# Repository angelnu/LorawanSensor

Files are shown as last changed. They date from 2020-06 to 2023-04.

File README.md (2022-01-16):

# STM32 Low Power LoraWan Sensors

This project provides a framework to easily build LoraWan devices. The requirements are:
- sensors that could run without replacing batteries during the life cycle of the device
- small size
- easy to build and program (need a 20-30)
- simple to create a new type: just a new file
- cost bellow 20€
- resist the outside weather with easy to 3D print cages

The sensor can work on a CR123 battery for 20 years (self-discharge of the battery being the main factor). It sends the battery voltage and (optionally) the temp of the MCU (using factory calibration).

For each new detected device it generates unique LoraWan keys and upload them to flash. This way the same firmware can be used for multiple instances of the same board.

**NOTE**: Do not put the config directory in a public repository. Instead save as extra home/private repository so you have versioning while keeping your keys private!

Download commands might be used to query or modify the configuration. See the commands section bellow.

## Bill of Materials
Devices can be built for ca 10-20€ ussing the following parts:
- STM32 MCU - any of the following:
  - STM32L412KB (3 €) - prefered: 128KB RAM for a future firmware OTA update
    - STM32L412KBT6 128K Flash,  8K RAM, LQFP-32
  - STM32L412K8 (2.5 €) - same as STM32L412KB but only 64K Flash
    - STM32L412K8T6 64K Flash,  8K RAM, LQFP-32
  - STM32L010K8 (1.5 €) - cheaper MCO+, slower, less memory, not tem and slightly higher consumption
    - STM32L412K8T6 64K Flash,  8K RAM, LQFP-32 
- RFM95W (3.5 € via Aliexpress, 3x this price if bought in Europe)
- RC123a battery and holder (2€ via Aliexpress, 2x this price if bought in Europe)
- PCB (2-5 € when ordering 12 from [Aisler](https://aisler.net) ) - see [Devices](devices) folder for the sources and the uploaded PCBs to [Aisler](https://aisler.net)
- 3D-printed boxes - see cages in [Devices](devices) folder
- some SMT components (1 €) - see schematics in [Devices](devices) folder

## Downlink commands

Downlink commands are used to query and/or modify the device settings without having to reprogram the flash. Each command uses one byte plus optional data depending on the command. The commands are implemtented in the `lorawan_process_command` at [lorawan.cpp](src/lorawan.cpp#L188)

Commands will be queued and transferred to the device after the next uplink transfer. Multiple commands can be queued but be carefull not to exceed to the watdown timeout or the device will get reset.

Commands:
- 0x00 - READ configuration
  - Description: Returns the configuration of the device. See [device_config_t](src/config.h#L23) for more details on the struct
  - Additional downlink bytes: none
  - Example output: 02 03 3C00 05 3C 6400 5802 01 0A 05 FF
- 0x01 - Reset config to the default
  - Additional downlink bytes: none
- 0x02 - Sets the configuration
  - Additional downlink bytes: config as returned by the 0x00 command
  - Example input: 02 02033C00053C64005802010A05FF
- 0x05 - Read Device UID
  - Additional downlink bytes: none
  - Output: 12 bytes with STM32 UID
- 0x06 - Read firmware GIT commit
  - Additional downlink bytes: none
  - Output: ASCII string
- 0x07 - Read firmware BUILD date
  - Additional downlink bytes: none
  - Output: ASCII string

## Firmware

This project requires [Platformio](https://platformio.org/) and the [STM32 Cube Programmer](https://www.st.com/en/development-tools/stm32cubeprog.html). Both need to be installed and available in the PATH.

Keys for each detected device will be stored under `config/devices.ini`. Before you run for the first time please create the file and include your app EUI (or modify afterwards). You can create this by registering a new app at the [TTN](https://console.thethingsnetwork.org/applications) console. The file should have:
```
[global]
appeui = <your app EUI>
```
If you run without creating the file first then the programmer will create a dummy APPEUI which you will need to modify. You can keep the config folder into its own git repository but please keep it private! On checkout you might use the [this script](checkout_keys_repo.sh) to check it out.

For programming either use the platformio UI or any of the CLI commands proposed for the device.

If you connect a serial interface while booting you should see the following:
```
Settings unchanged
DEVICE VERSION: 3
DEVICE CONFIG: 0x02033C00053C64005802010A05FF
Device UID: 0x3200230006504D3843353720
BUILD DATE: Jun 21 2020
BUILD TIME: 18:07:48
COMMIT ID: e3d1d3b5d34d39d88d90022d6fe365ebce3887b5
APPEUI: 0x.....
DEVEUI: 0x....
Starting
7579 Sending.. 18248 TX_COMPLETE
```

## Adding new devices

1. Add a section to `platformio.ini` for your device. The key part is to have a dedicated `-D SENSOR_<PCB name>_<sensor name>_<MCU name>` (such as `-D SENSOR_GENERIC_DISTANCE_SMT32`) -> this will be needed in the next step.
  - If you are just using the generic PCB then you can copy `Basic v1` and modify to your needs
  - If you are creating your own PCB based on the STM32 MCU then you can copy `Generic v1` and modify to your needs
  - If you use a different MCU then you will need to create your own target extending `base` and `base_debug`. Please notice that you will in this case have to add support for the new MCU in multiple areas of the code where the MCU is relevant: the code has been tested with STM32 (mainly) and atmega32.
2. Add a new cpp file to `src/devices/` for your new device. The namming convention is <PCB type>_<device name>_<MCU family>.cpp. If you are using a STM32 CPU you should consider copying `generic_basic_stm32.cpp` which does not depend on any external sensors to work and then add your own sensors to it. You need to make this file to only get included and compiled when `SENSOR_<PCB name>_<sensor name>_<MCU name>` is defined.
3. Add to `devices.h` a section for your device where you set your `device_config_device_t`. This struct includes what persistent settings your device needs. These settings can later be modified via a LORAWAN command.
4. Documment your device in the `devices` folder. This folder structure is:
   - _<PCB name>_
     - _cages_: instructions and files to 3D print cages for devices
     - _KiCad_: Schematics and PCBs created with KiCad
     - _pictures_: pcitures embedded in markdown readme
     - _README_: instructions, pictures and links for devices. It is structured with a chapter for each device sharing the same PCB and a subcharter for each mayor version of the device. 

## ToDos
- Firmware OTA update

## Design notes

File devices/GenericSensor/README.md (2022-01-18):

# Generic Sensor PCB

This device exposed all available GPIOs from the 32 pin STM32 so external sensors can be attached. Multiple use cases are listed bellow.

- GenericSensor_PCB_full_view

## Versions of the PCB

### Generic Sensor v2

This verssion is backwards compatible (same posssitions for all components, even the v1 stencil might be used) but adds support for additional pull-ups or pull-downs. Check the schematic bellow to understand the options: there are two sets of solder jumpers that allow pull-up or pull-down selection. Also using 0R you can enable additional 3V and GND outputs.

- [Aisler PCB project](https://aisler.net/p/LVXPWPMZ)
- [PCB STEP model](KiCad/GenericSensor_v2.step)
- [KiCad model](KiCad\GenericSensor_v2-backups/GenericSensor_v2.kicad_pro)
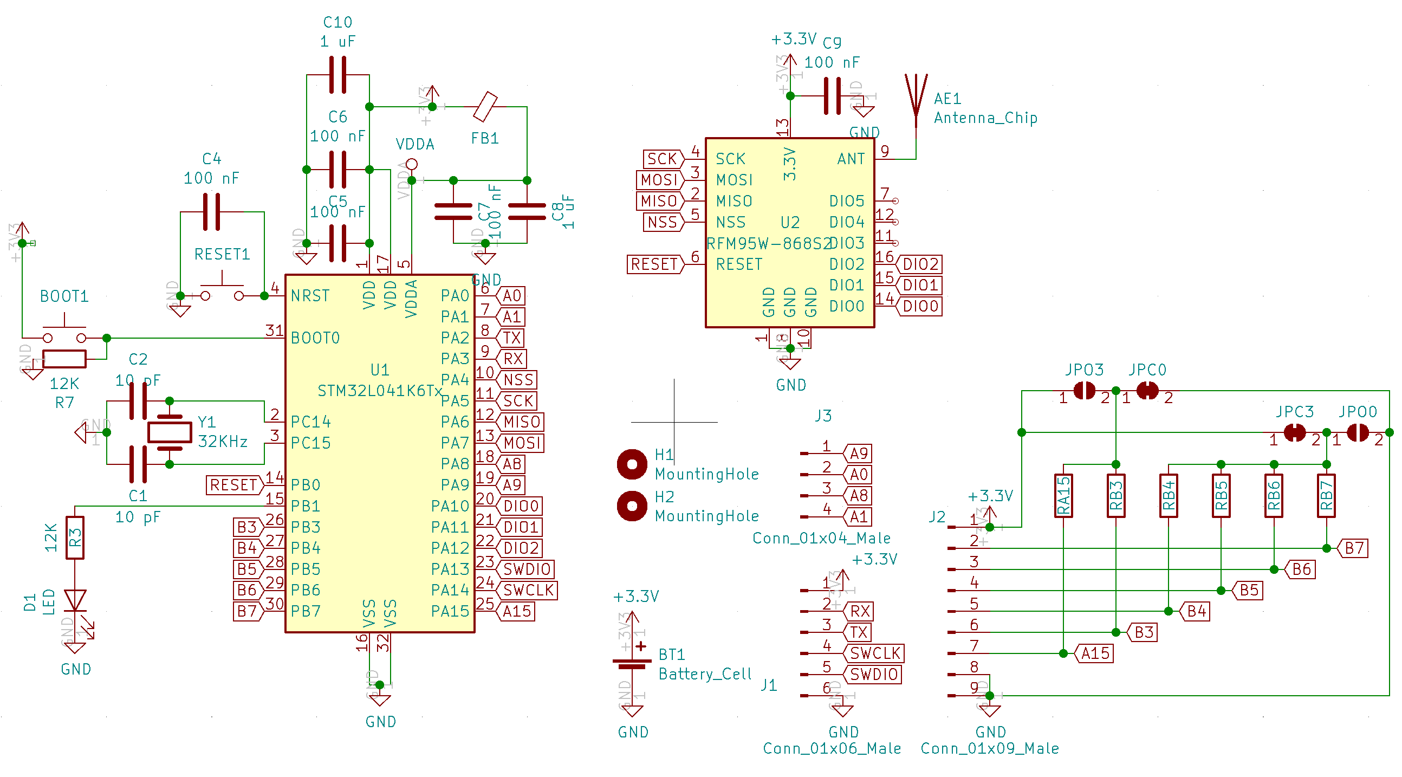
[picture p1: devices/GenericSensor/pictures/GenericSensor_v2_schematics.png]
Schematics Preview
- 
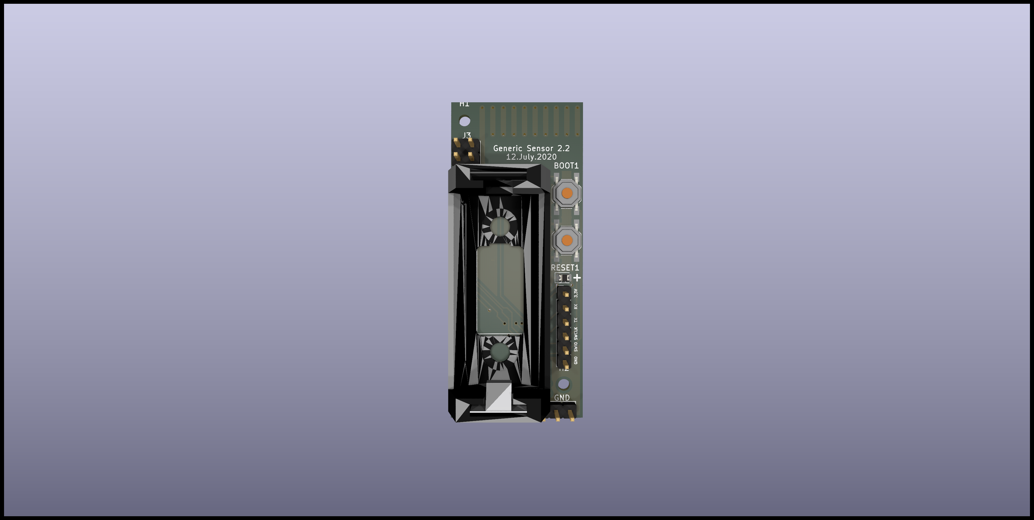
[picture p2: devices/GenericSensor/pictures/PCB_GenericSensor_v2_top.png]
PCB Top render
- 
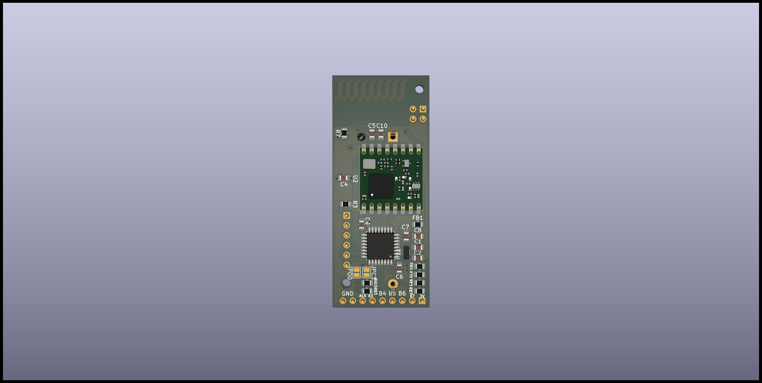
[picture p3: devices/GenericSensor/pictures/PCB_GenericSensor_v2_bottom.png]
PCB Bottom render
- 

### Generic Sensor v1

This is the first version without any unneded HW. It is optimised to make it easy to esamble with only the programing pins and the battery holder not being SMD components. It does not external pull-ups so it relays into the internal ones in the MCU -> this is not the best for battery life (40 KOhms drag ca 75 uA) so v2 was develop to allow use larger (such as 10 MOhms) instead.

Since v2 is backwards compatible there is no need to use v1 anymore.

- [Aisler PCB project](https://aisler.net/p/YFVFQBHD)
- [SoilSensor.sch](KiCad/GenericSensor_v1.sch)
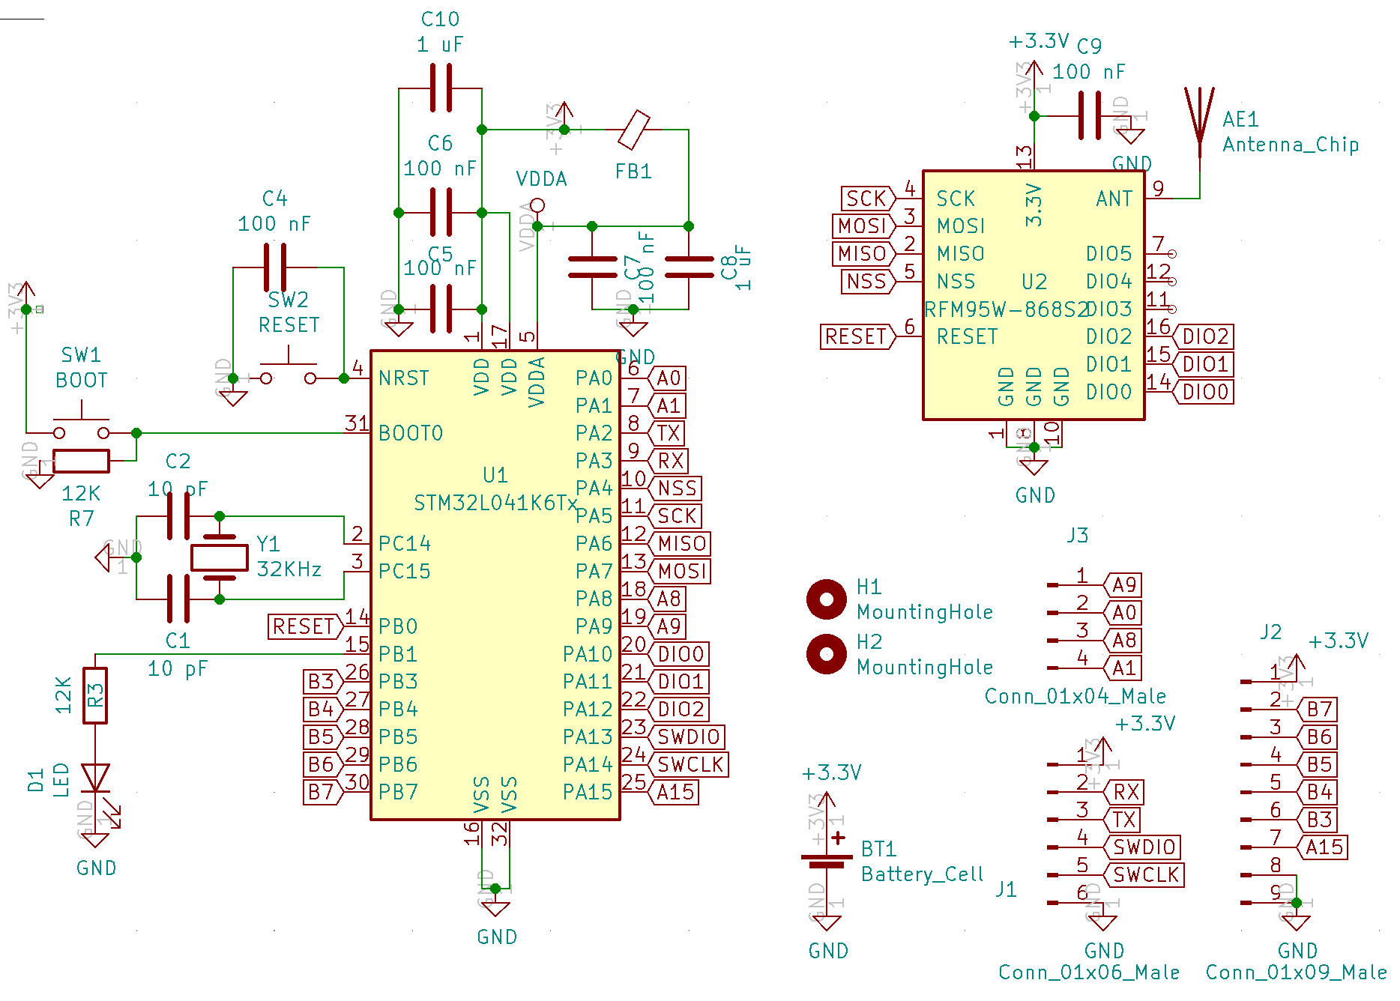
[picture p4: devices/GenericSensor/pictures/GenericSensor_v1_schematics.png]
Schematics Preview
  - 
- [SoilSensor.kicad_pcb](KiCad/GenericSensor_v1.kicad_pcb)

## Use Cases

## Basic v1

This is mainly for debugging and as base for the other use cases. It is just the generic sensor and its embedded battery and temperature sensors.
- Sensor: none extra, just battery voltage and temperature
- Power consumption:
  - measurements: 0,4 mA, 30 ms, 1 measurement/minute
  - transmission: 120 mA, 50 ms, sending once/hour
  - iddle: 300 uA, 2 s, sending once/hour
  - deep sleep: 2 uA
  - battery: 1400 mAh
  - theoretical batery live (no auto-discharge): 39 years
- PINs: none of the external pins used
- Firmware:
  For programming either use the platformio UI or any of the following CLI commands:
  - `pio run -t upload -e generic_basic_v1` - PCB v2, STM32 L4
  - `pio run -t upload -e generic_basic_v1_debug` - PCB v2, STM32 L4, debug
- [3D Printed cage](cages):
  - None
- BUGS:
  - None so far

### Distance Sensor v1

Used to detect when a car is parked in a parking lot.

- Sensor:
  - Lidar [vl53l1x](https://www.st.com/en/imaging-and-photonics-solutions/vl53l1x.html): consumption small enough to be powered through a PIN without a mosfet - not low power enough to keep power during deep sleep. It can measure up to 4 meters.
    - Used [Melopero board](https://www.melopero.com/shop/sensori/prossimita/melopero-vl53l1x-time-of-flight-long-distance-ranging-sensor-breakout/) since it was quickly available in Amazon
    - Ordered some with cover from [China](https://de.aliexpress.com/item/4000110308676.html)
- Power consumption:
  - measurements: 1,5 mA, 120 ms, 1 measurement/minute
  - transmission: 120 mA, 50 ms, sending once/hour
  - iddle: 300 uA, 2 s, sending once/hour
  - deep sleep: 2 uA
  - battery: 1400 mAh
  - theoretical batery live (no auto-discharge): 23 years
- PINs:
  - PB7 -> vl53l1x I2C SDA
  - PB6 -> vl53l1x I2C SCL
  - PB5 -> vl53l1x VIN
  - GND -> vl53l1x GND
- Firmware:
  For programming either use the platformio UI or any of the following CLI commands:
  - `pio run -t upload -e distance_v1` - PCB v2, STM32 L4
  - `pio run -t upload -e distance_v1_debug` - PCB v2, STM32 L4, debug
- [3D Printed cage](cages/distance):
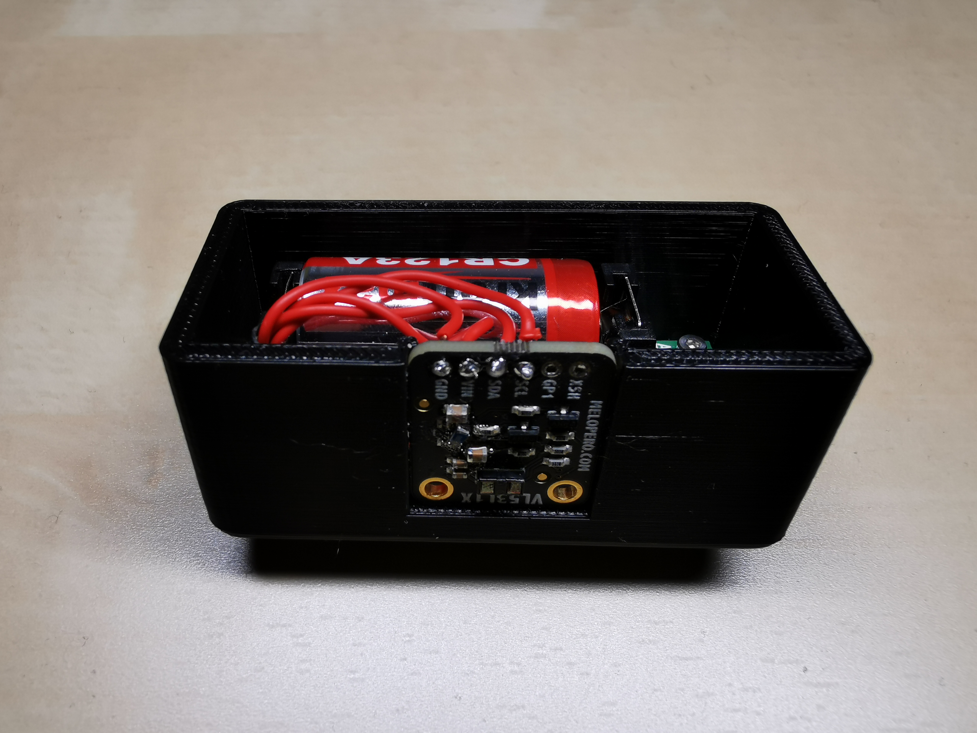
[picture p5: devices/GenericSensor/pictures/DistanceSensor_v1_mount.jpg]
Cage Mount
  - 
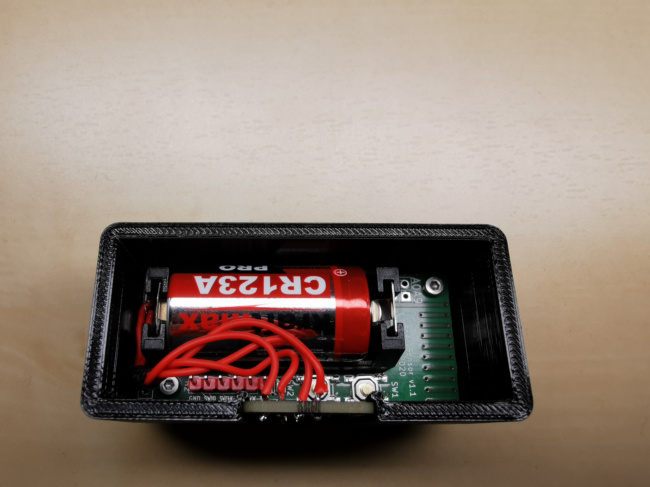
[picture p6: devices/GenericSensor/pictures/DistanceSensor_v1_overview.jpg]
PBC view
  - 
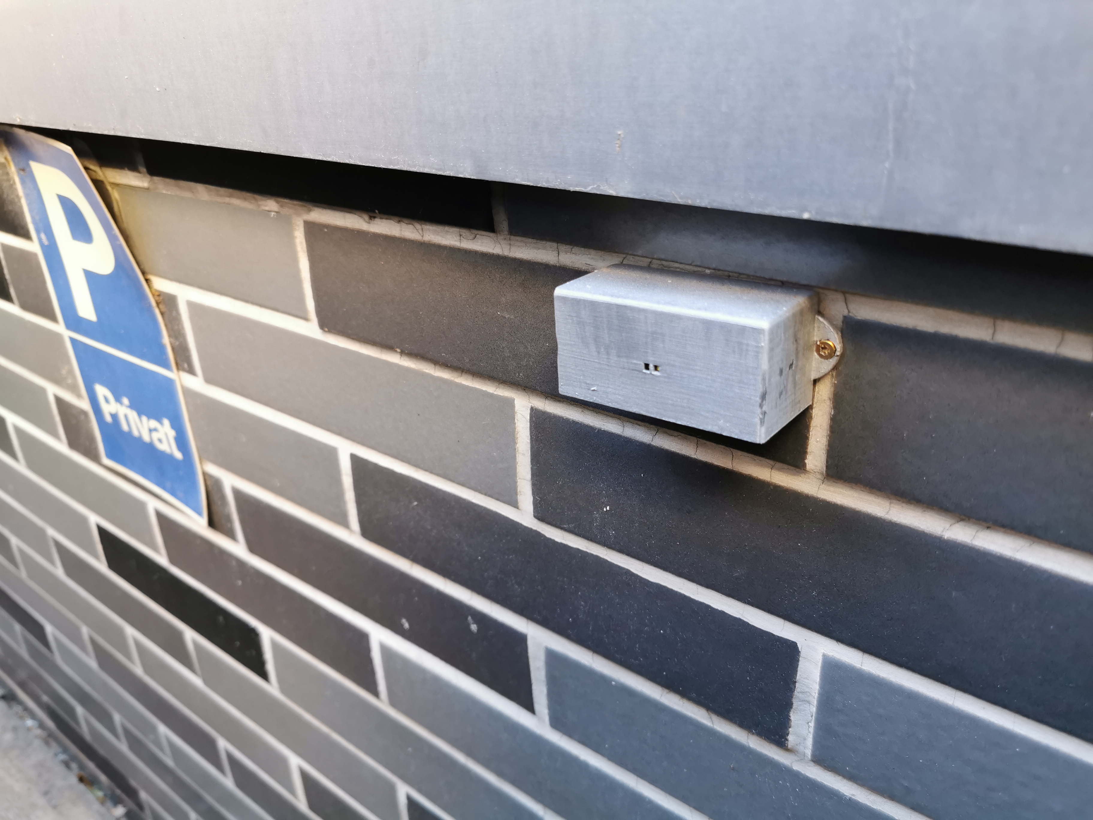
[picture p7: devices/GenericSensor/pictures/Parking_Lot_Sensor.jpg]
Mounted Cage
  - 
- BUGS:
  - None so far
  
### Door Sensor v1

This sensor tracks the state (open/closed) of up to 4 doors or windows. It supports two modes:
- simple: the state of the door/window is directly reported as soon as it changes
- perssistent mode (or post-mode): once the door is opened once is reported as open even if it gets closed afterwards. A second sensor is used to reset the reported door status back to closed. The reset is typically associated to a second door used to pick up the post but it could also get connected to a button that plays the same role.

- Sensor:
  - 1-8 x [Reed Contact N/O Magnetic Induction Switch](https://www.amazon.de/gp/product/B07SZDGXLC): this switch reports open so far no magnet is close. This would correspond to the door/window being open.
  - 1-8 x Circular magnet
  - 1-8 x 10 MOhms resistor
- Power consumption:
  - measurements: 1,5 mA, 40 ms, 2 measurement/day (post mode)
  - transmission: 120 mA, 50 ms, sending 2/day
  - iddle: 300 uA, 2 s, sending once/hour
  - deep sleep: 2 uA + (0.3 * number_of_sensors)
  - battery: 300 mAh
  - theoretical batery live (no auto-discharge): 23 years
- PINs (using PCB v1): each sensor needs a big (10 MOhm resistor) pull-up.
  - VCC  -> pull-up resistors
  - PB7  -> cannot be used for interrupts - conflicts with MOSI
  - PB6  -> cannot be used for interrupts - conflicts with MISO
  - PB5  -> pull-up resistor (RB5) and door 1 reed switch
  - PB4  -> pull-up resistor (RB4) and door 1 reset reed switch
  - PB3  -> pull-up resistor (RB3) and door 2 reed switch
  - PA15 -> pull-up resistor (RA15) and door 2 reset reed switch
  - PA0  -> pull-up resistor (external) and door 3 reed switch (need to uncomment in `platformio.ini`)
  - PA1  -> pull-up resistor (external) and door 3 reset reed switch (need to uncomment in `platformio.ini`)
  - PA8  -> pull-up resistor (external) and door 4 reed switch (need to uncomment in `platformio.ini`)
  - PA9  -> pull-up resistor (external) and door 4 reset reed switch (need to uncomment in `platformio.ini`)
  - GND -> reed switches
- PINs (using PCB v2) for 2 doors:
  - VCC: not used
  - RB7, RB6, RB5, RB4: 10 MOhms (0805 type)
  - RB3, RA15: 0R (0805 type)
  - Solder jumpers umodified
  - PB7  -> door 1 reed switch
  - PB6  -> reset for door 1 (or door 3) reed switch
  - PB5  -> door 2 reed switch
  - PB4  -> reset for door 2 (or door 4) reed switch
  - PB3, PA15 and both GNDs: any of the above reed switches
- Firmware:
  For programming either use the platformio UI or any of the following CLI commands:
  - `pio run -t upload -e distance_v1` - PCB v2, STM32 L4
  - `pio run -t upload -e distance_v1_debug` - PCB v2, STM32 L4, debug
- [3D Printed cage](cages/door):
  - [Fusion 360 file](https://a360.co/3GygWqv)
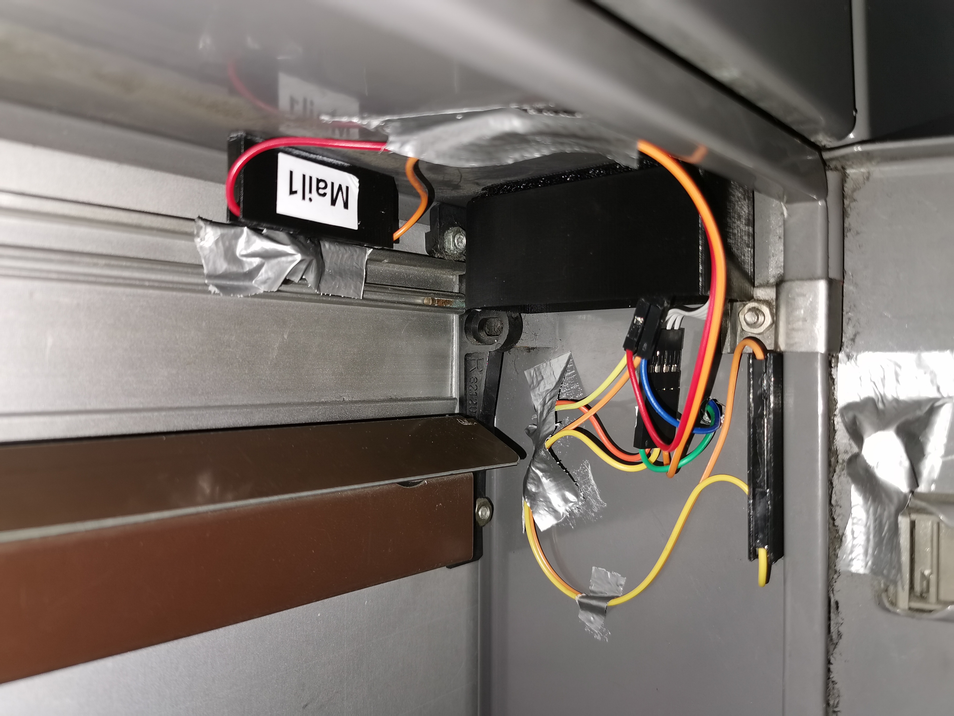
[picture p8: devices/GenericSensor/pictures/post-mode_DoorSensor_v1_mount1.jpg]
Mounted Cage view 1
  - 
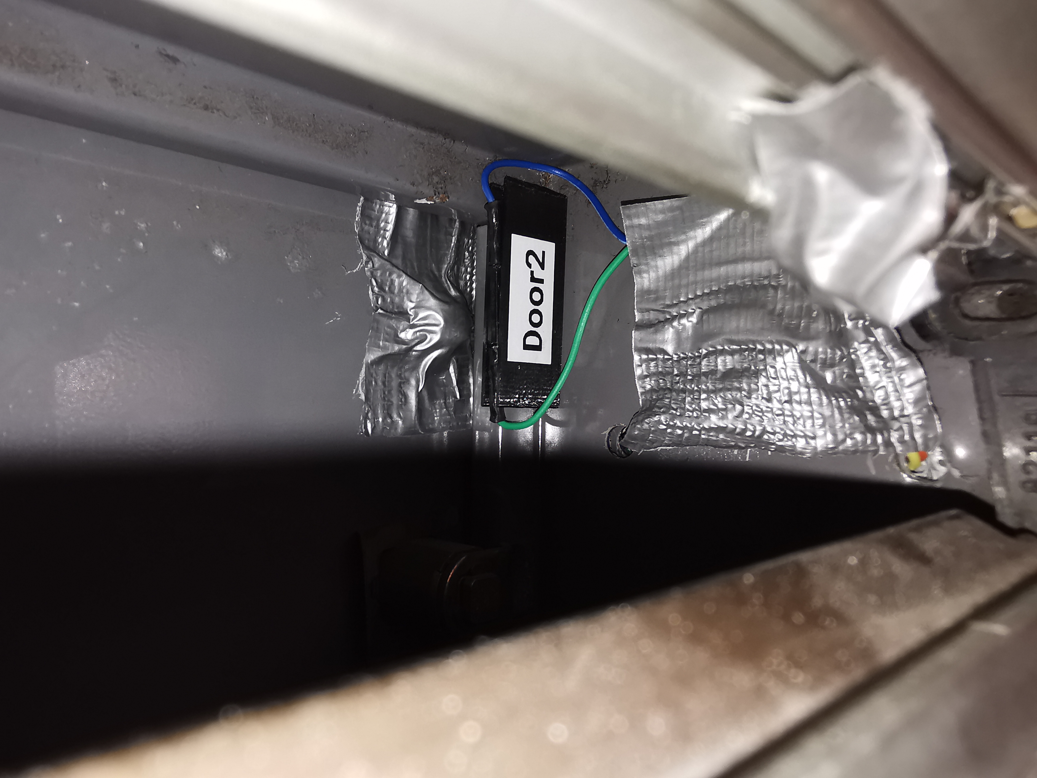
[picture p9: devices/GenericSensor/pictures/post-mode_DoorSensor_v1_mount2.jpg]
Mounted Sensor view 2
  - 
- BUGS:
  - None so far

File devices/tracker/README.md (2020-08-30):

# Tracker

This is a GPS tracker including a move sensor and a distance sensor (not in the PCB). It also routes most of the MCU pins to a connector so additional sensors might be connected.

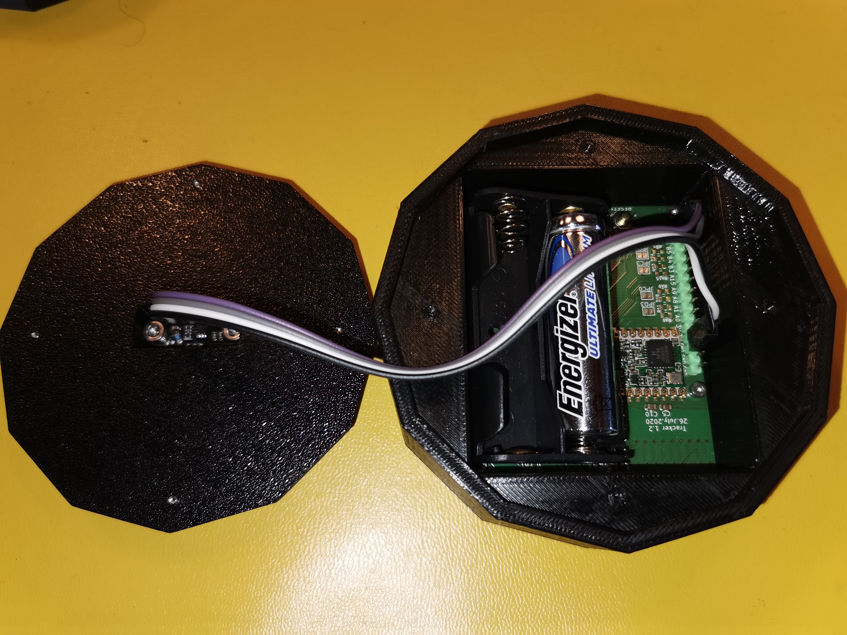
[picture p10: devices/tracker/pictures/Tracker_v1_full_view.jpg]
Full mount Tracker v1
- 

## Tracker v1 (WIP)

In this version a distance sensor is also used to measure the gasoil level in a vehicle.

This is Work In Progress - Firmware not ready and PCB not tested yet.

- [Aisler PCB project](https://aisler.net/p/XNCQBQQY)
- [Tracker.sch](KiCad/tracker_v1.sch)
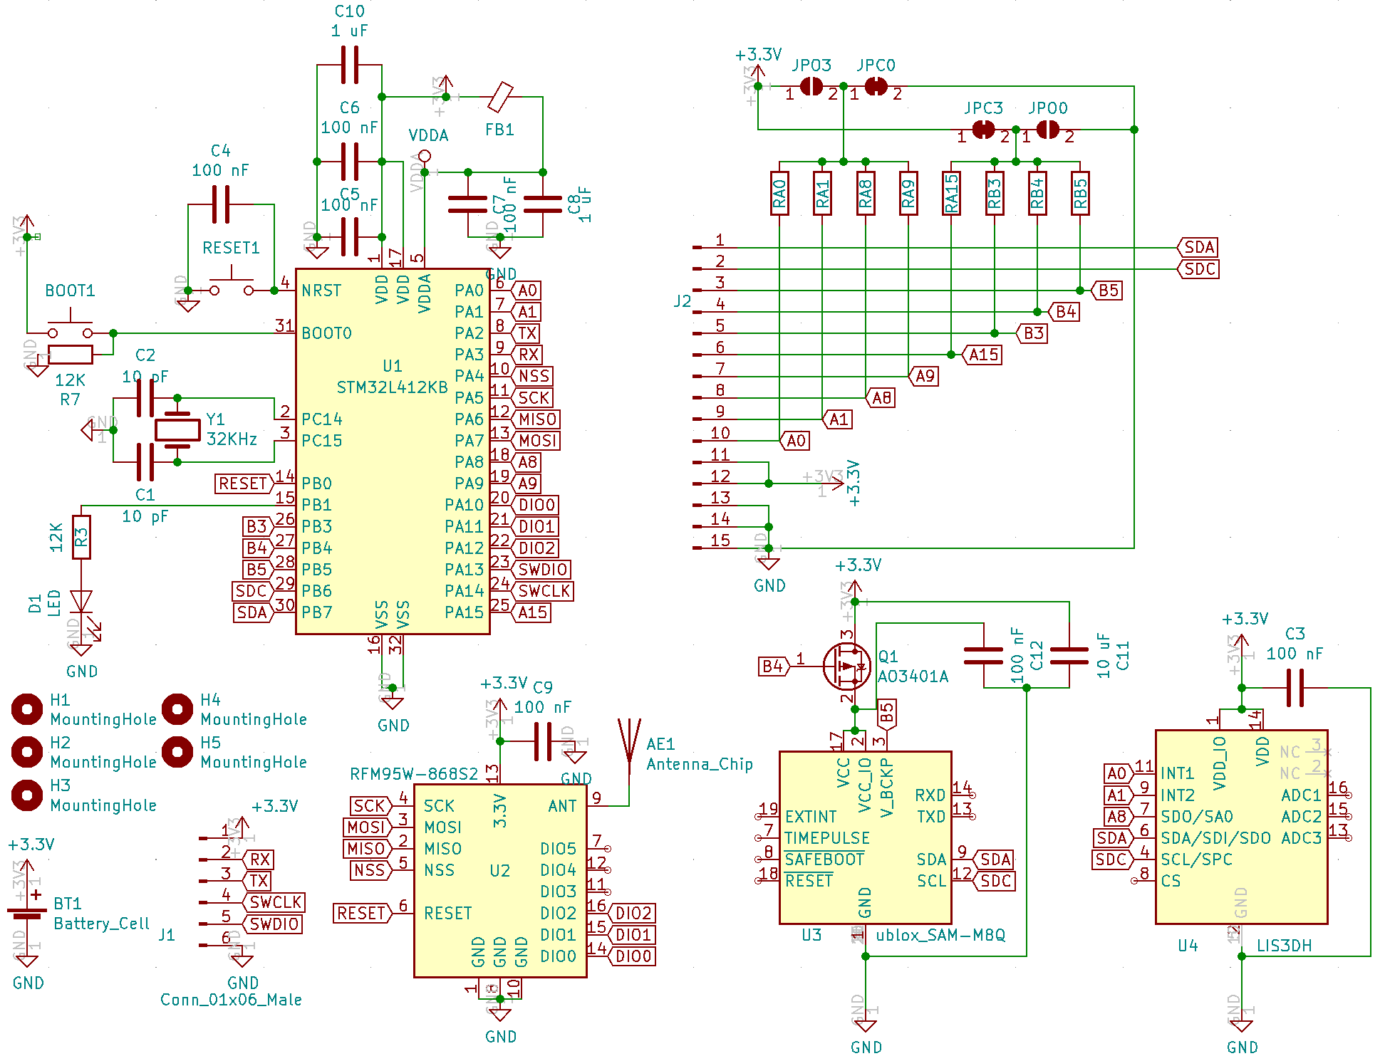
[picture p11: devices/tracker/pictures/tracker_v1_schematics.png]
Schematics Preview
  - 
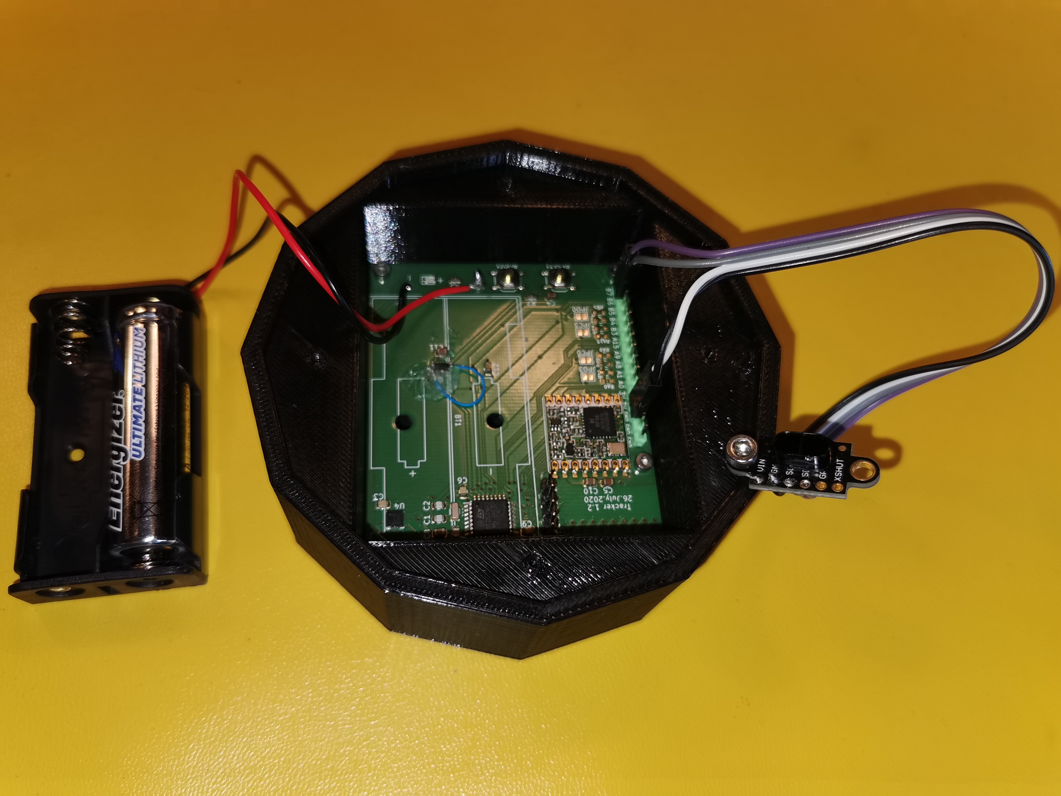
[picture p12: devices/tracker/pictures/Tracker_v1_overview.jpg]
PCB Overview
  - 
  - PCB Close View Front
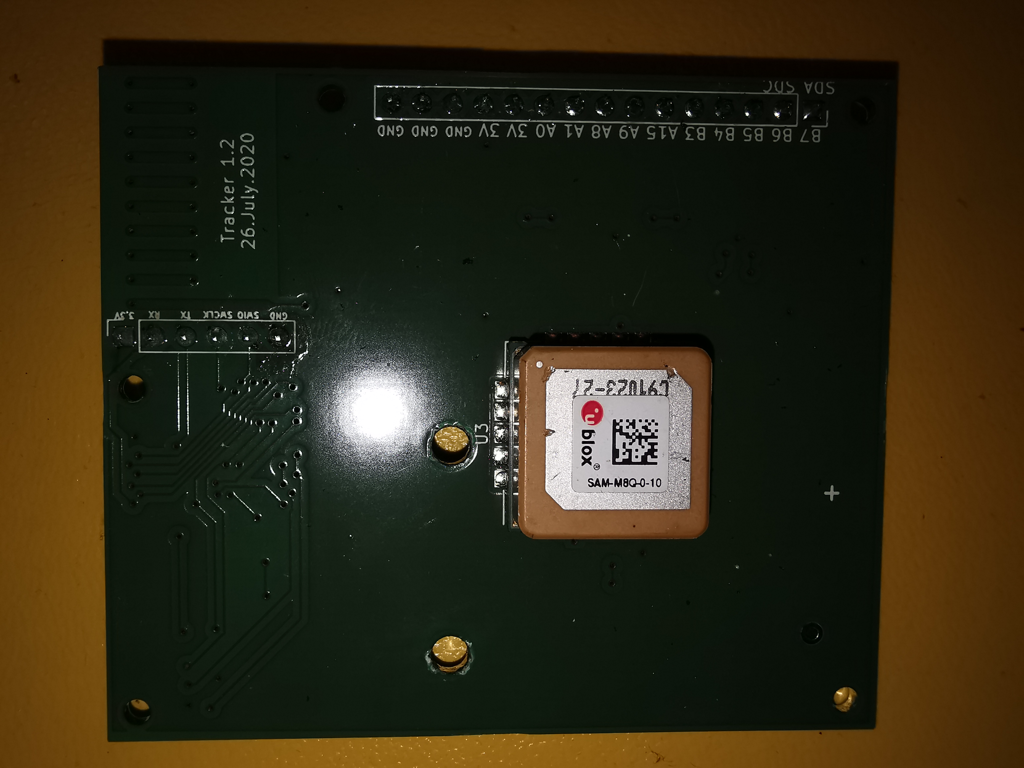
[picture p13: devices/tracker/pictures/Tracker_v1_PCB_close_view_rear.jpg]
PCB Close View Rear
  - 
- [Traker.kicad_pcb](KiCad/tracker_v1.kicad_pcb)
- Sensor:
  - GPS [ublox_SAM-M8Q](https://www.u-blox.com/en/product/sam-m8q-module)
    - low-power: 15 uA to keep memory and clock - most important factor for battery life
    - very quick on hotfix - 1s
    - supports GPS, Galileo and Glonax
    - high sesitivity - after a fix I even get signal indoors
    - relatively expensive (20€)
  - Accelerometer [LIS3DH](https://www.st.com/en/mems-and-sensors/lis3dh.html)
    - ultra low-power so we can keep on and wake up GPS only when movement is detected
    - low cost (1,5€)
  - Lidar [vl53l1x](https://www.st.com/en/imaging-and-photonics-solutions/vl53l1x.html): consumption small enough to be powered through a PIN without a mosfet - not low power enough to keep power during deep sleep. It can measure up to 4 meters.
    - Ordered some with cover from [China](https://de.aliexpress.com/item/4000110308676.html)
    - Alternative: [Melopero board](https://www.melopero.com/shop/sensori/prossimita/melopero-vl53l1x-time-of-flight-long-distance-ranging-sensor-breakout/) more expensive but available in Amazon.
- Power consumption:
  - measurements: TBD, 1 measurement/day when not moving, 6 measurements per hour when moving
  - transmission: 120 mA, 50 ms, sending once/12 hours
  - iddle: 300 uA, 2 s, sending once/hour
  - deep sleep: 17 uA (mainly GPS)
  - battery: 3000 mAh
  - theoretical batery live (no auto-discharge): 19 years
- PINs:
  - PB7 -> vl53l1x I2C SDA
  - PB6 -> vl53l1x I2C SCL
  - PB3 -> vl53l1x VIN
  - GND -> vl53l1x GND
- Firmware:
  For programming either use the platformio UI or any of the following CLI commands:
  - `pio run -t upload -e tracker_v1` - PCB v2, STM32 L4
  - `pio run -t upload -e tracker_v1_debug` - PCB v2, STM32 L4, debug
- [3D Printed cage](cage):
  - PCB Mount
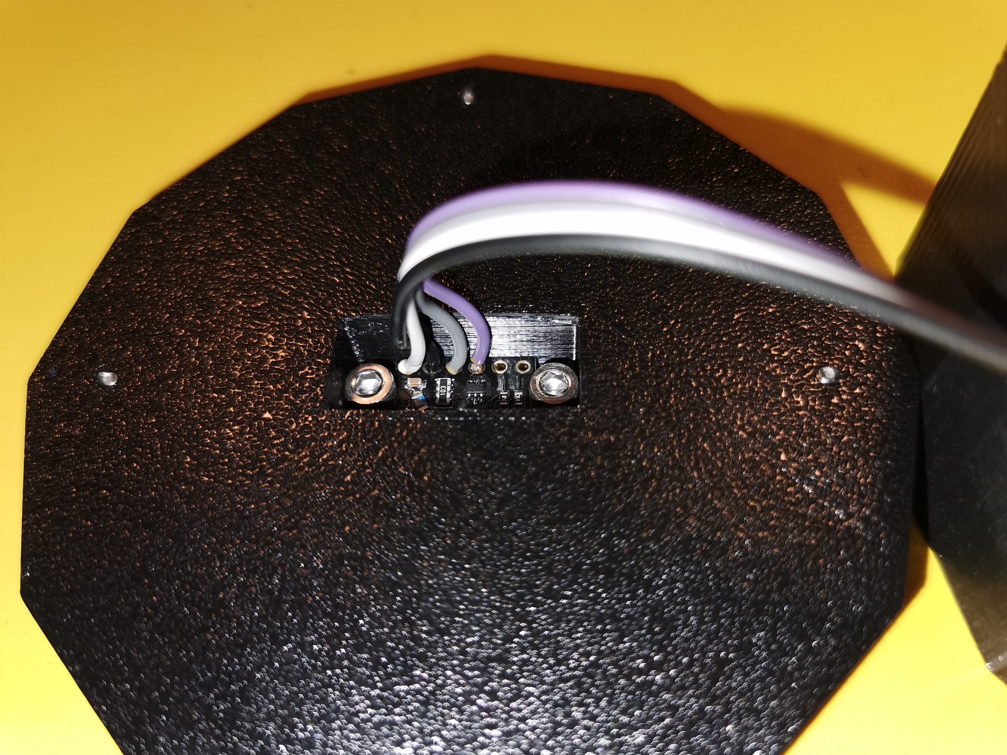
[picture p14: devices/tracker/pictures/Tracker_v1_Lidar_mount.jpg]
Lidar Mount
  - 
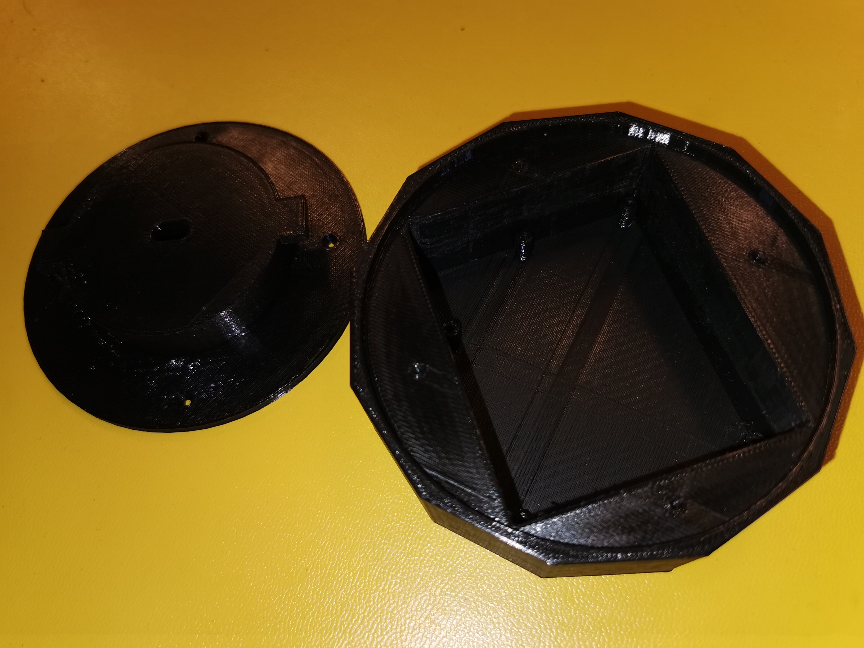
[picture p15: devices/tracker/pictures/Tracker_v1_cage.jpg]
Cage Preview
  - 
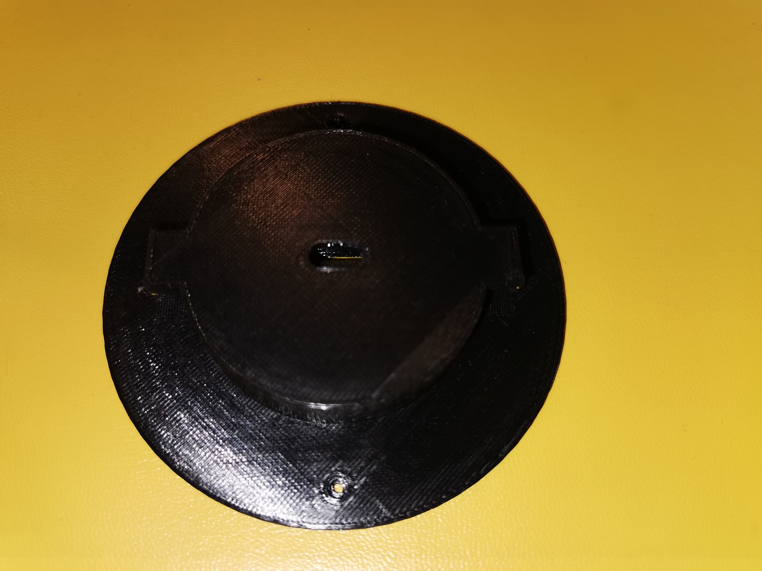
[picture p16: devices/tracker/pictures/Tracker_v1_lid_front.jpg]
Cage Lid Front
  - 
  - Cage Lid Rear
- BUGS:
  - None so far

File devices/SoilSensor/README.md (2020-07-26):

# Capacitive Soil Sensor

This device includes a capacitive sonde in the same PCB. The resulting device can measure the soil moisture without beeing corroded nor being affected by the temperature as the resistive soil sensors.

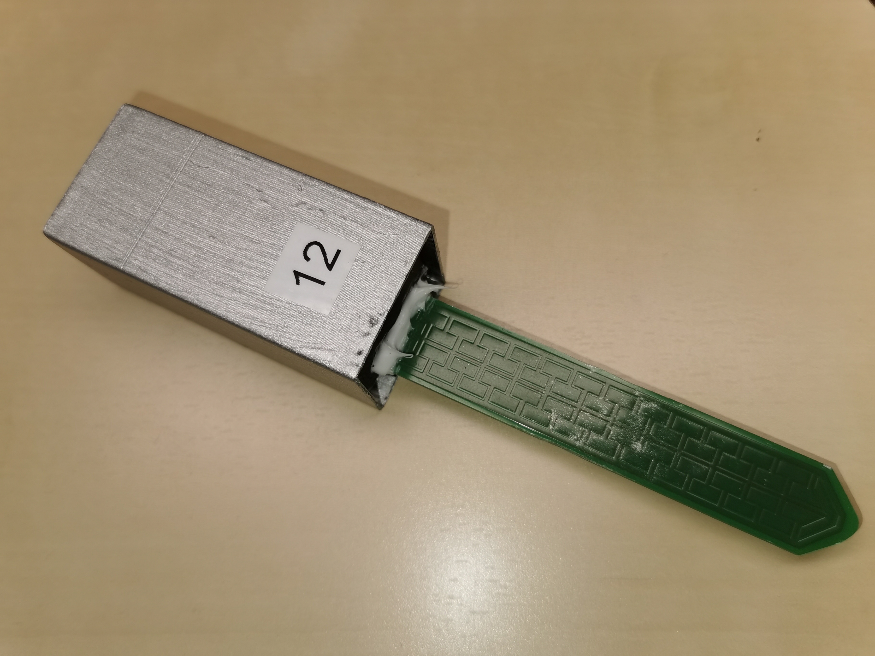
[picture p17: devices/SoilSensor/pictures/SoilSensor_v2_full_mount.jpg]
Full mount SoilSensor
- 

## Power cosumption

- sleep: 1.5 uA
- run: 415 uA at 4 MHz - 20 ms for measurement - 2 seconds waiting for reception
- Sending; 120 mA during 50 ms
- Sending each 60 minutes (at least moisture level changess fast - watering, raining)
- Battery: 1400 mAh
  
The above gives a theorical batery life of 47 years without auto-discharge. In reality the auto-discharge effect is expected to be the predominant one defining the live of the device to around 20 years for a good quality battery.

## References

- Moisture sensors
  - https://hackaday.io/project/161994-mesh-network-soil-moisture-sensor
  - https://flashgamer.com/blog/comments/testing-capacitive-soil-moisture-sensors
  - https://www.thethingsnetwork.org/labs/story/a-cheap-stm32-arduino-node
- Touch sensors
  - using two pins: https://github.com/PaulStoffregen/CapacitiveSensor
    - this is what it used here
  - STM32 - https://github.com/arpruss/ADCTouchSensor
    - based on https://github.com/martin2250/ADCTouch

## Versions

### Soil Sensor v2

This is the (currently) final version without any unneded HW. It is optimised to make it easy to esamble with only the programing pins and the battery holder not being SMD components.

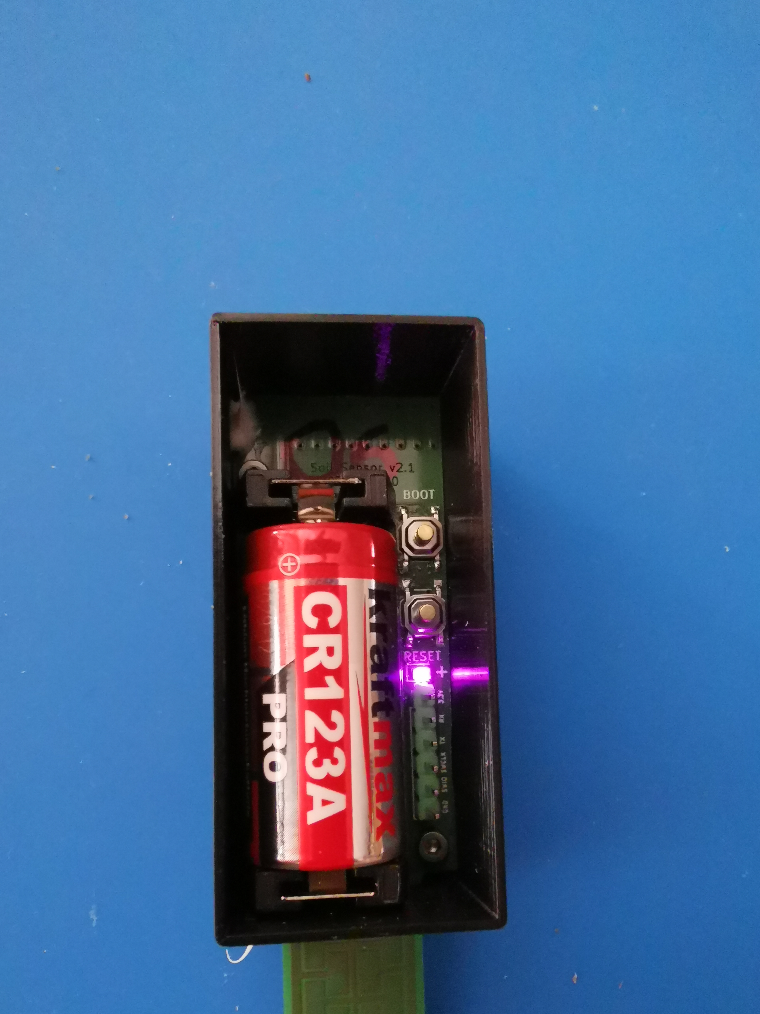
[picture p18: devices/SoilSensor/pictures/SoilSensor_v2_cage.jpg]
Full mount SoilSensor v2
- 

- [Aisler PCB project](https://aisler.net/p/DFIQTREA)
- [SoilSensor.sch](KiCad/SoilSensor_v2.sch)
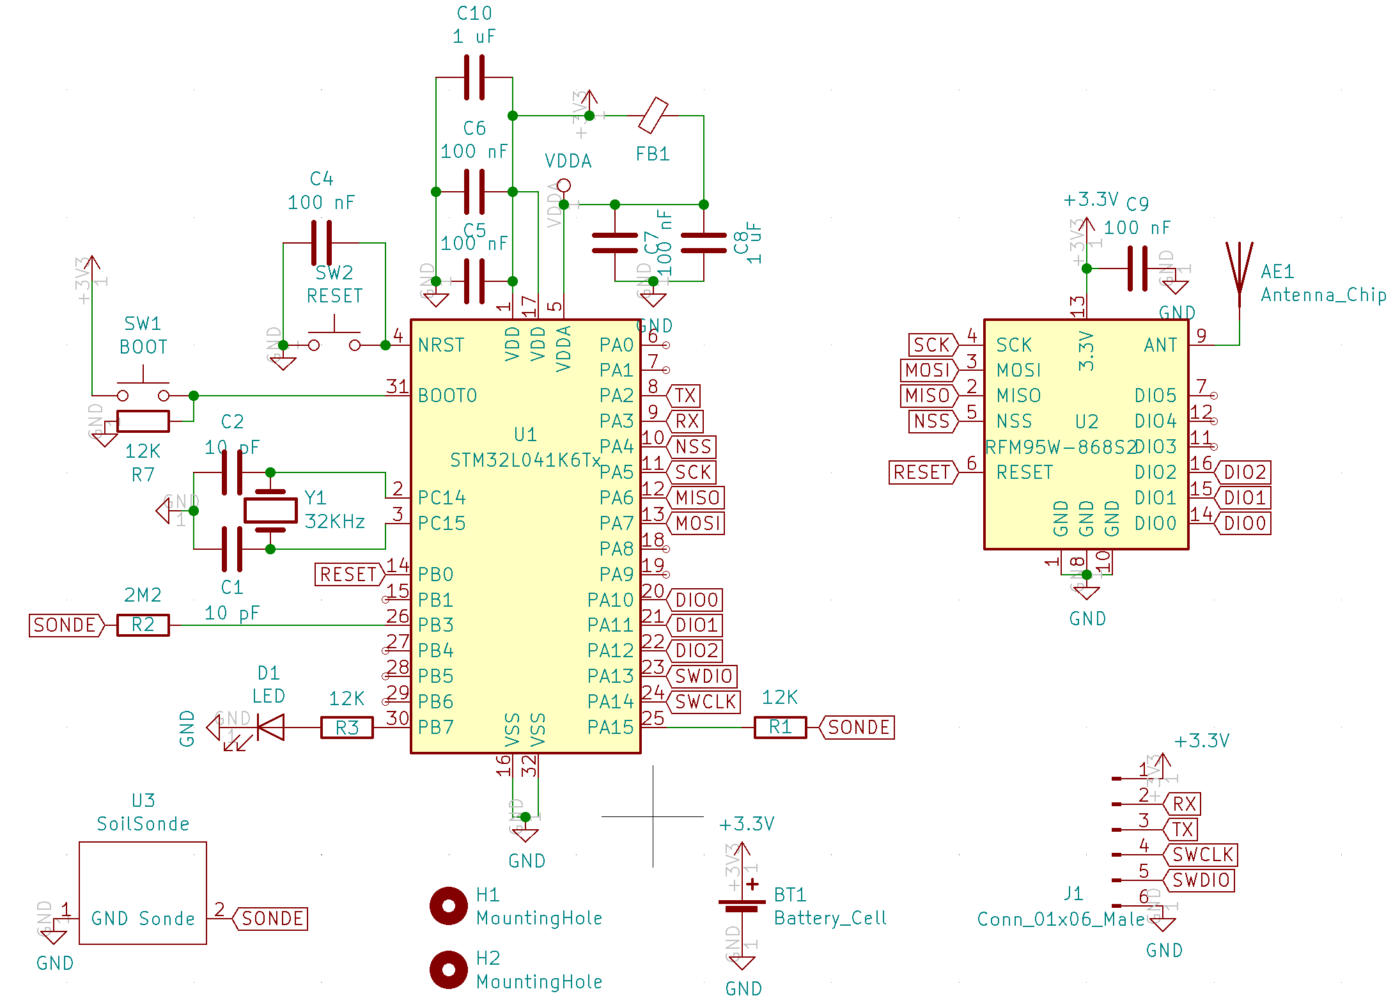
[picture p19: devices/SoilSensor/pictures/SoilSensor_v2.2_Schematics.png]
Schematics Preview
  - 
- [SoilSensor.kicad_pcb](KiCad/SoilSensor_v2.kicad_pcb)
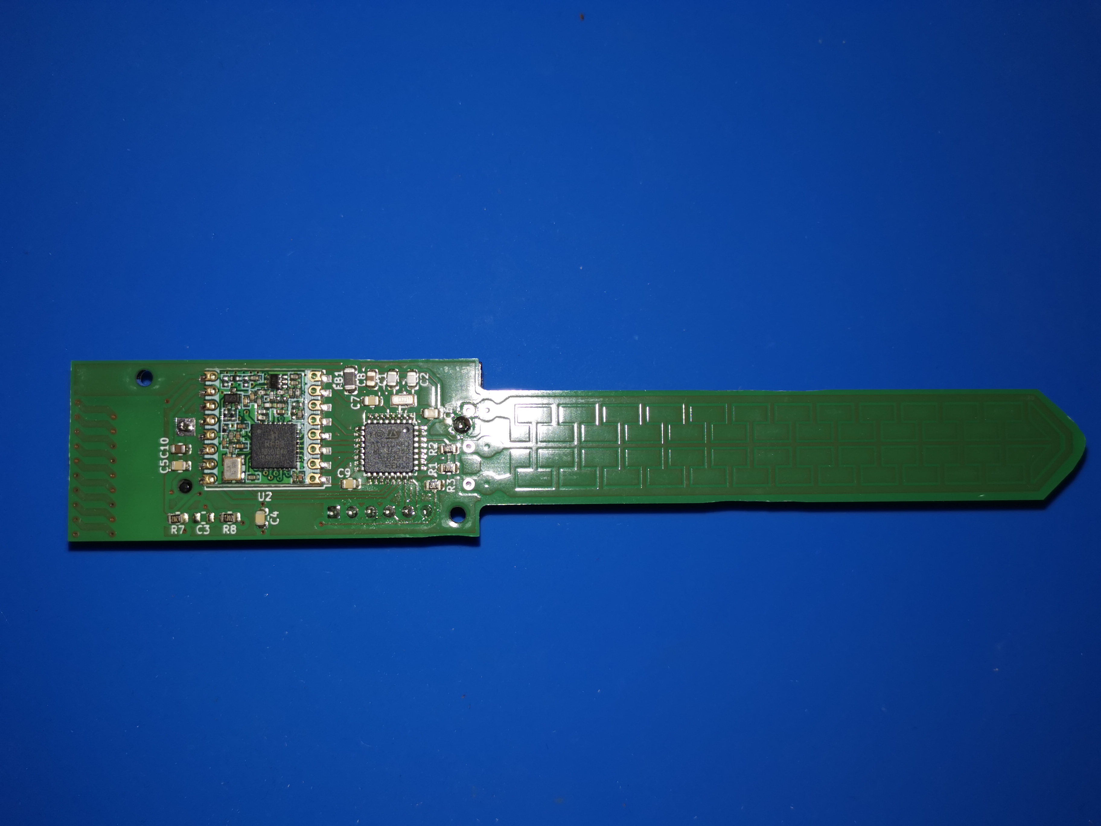
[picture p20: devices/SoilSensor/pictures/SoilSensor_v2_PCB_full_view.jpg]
PCB Full View
  - 
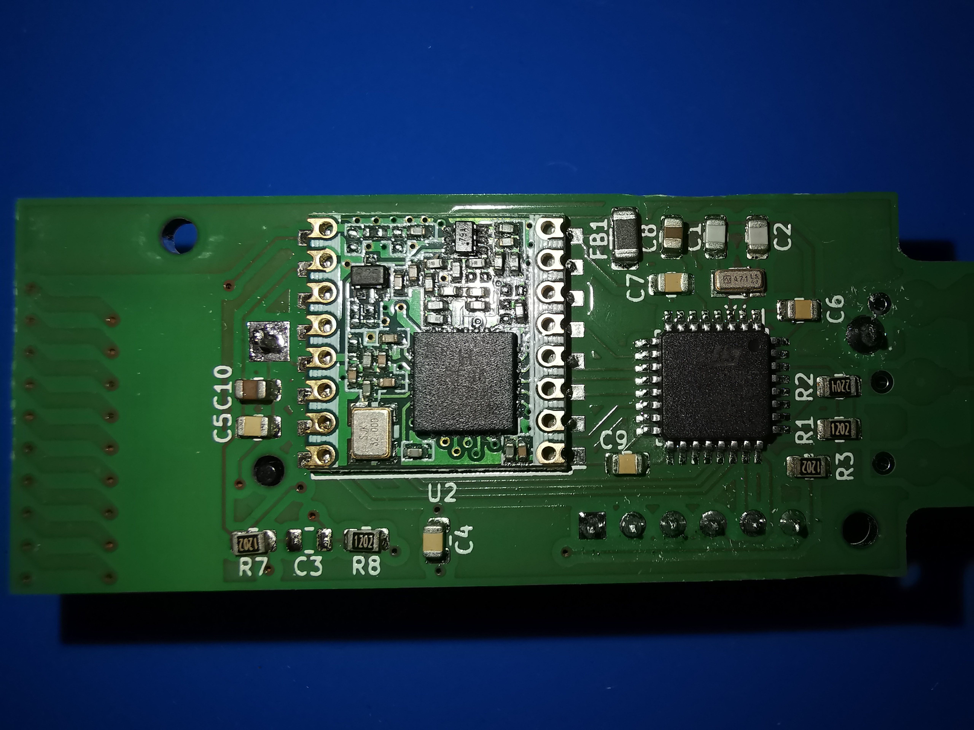
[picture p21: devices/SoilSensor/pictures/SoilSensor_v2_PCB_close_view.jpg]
PCB Close View
  - 
  - [SVG for soil sonde](pictures/soilSonde.svg)
    - edited with [Inkscape](https://inkscape.org)
    - imported to KiCad with [svg2shenzhen](https://github.com/badgeek/svg2shenzhen) plugin.
    - Sonde Preview
- Firmware:
  For programming either use the platformio UI or any of the following CLI commands:
  - `pio run -t upload -e soilsensor_v2_L4` - PCB v2, STM32 L4
  - `pio run -t upload -e soilsensor_v1_L4` - PCB v1, STM32 L4
  - `pio run -t upload -e soilsensor_v1_L0` - PCB v1, STM32 L0
- [3D Printed cage](cage) sealed with silicone:
  - Cage Preview
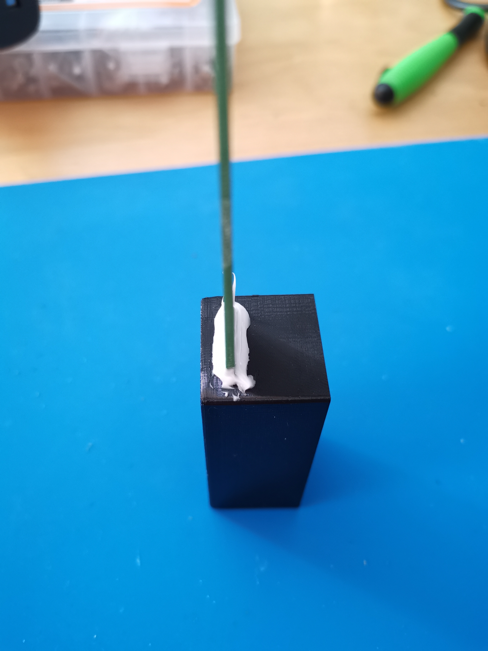
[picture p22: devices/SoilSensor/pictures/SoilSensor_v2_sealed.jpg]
Cage Sealed
  - 
- BUGS:
  - C3 (the condensator for the BOOT selector) should have been connected to GND instead of VCC to avoid starting the bootloader first time we connect the battery. Not soldering it works fine so need for a new revision.

## Soil Sensor v1

This was the first version on STM32. It has multiple debug options so more complex than needed. Battery is connected with Dupont cables.

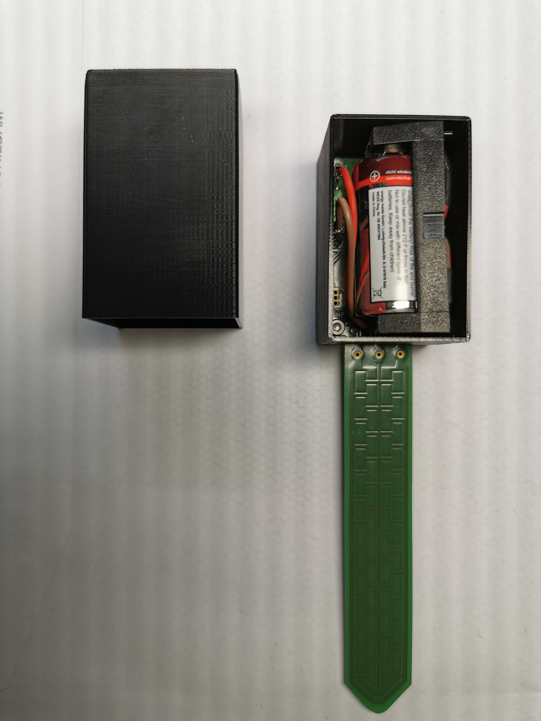
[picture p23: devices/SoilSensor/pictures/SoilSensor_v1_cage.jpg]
Full mount SoilSensor v1
- 

- [Aisler PCB project](https://aisler.net/p/FEKNZTQA)
- [SoilSensor.sch](KiCad/SoilSensor.sch)
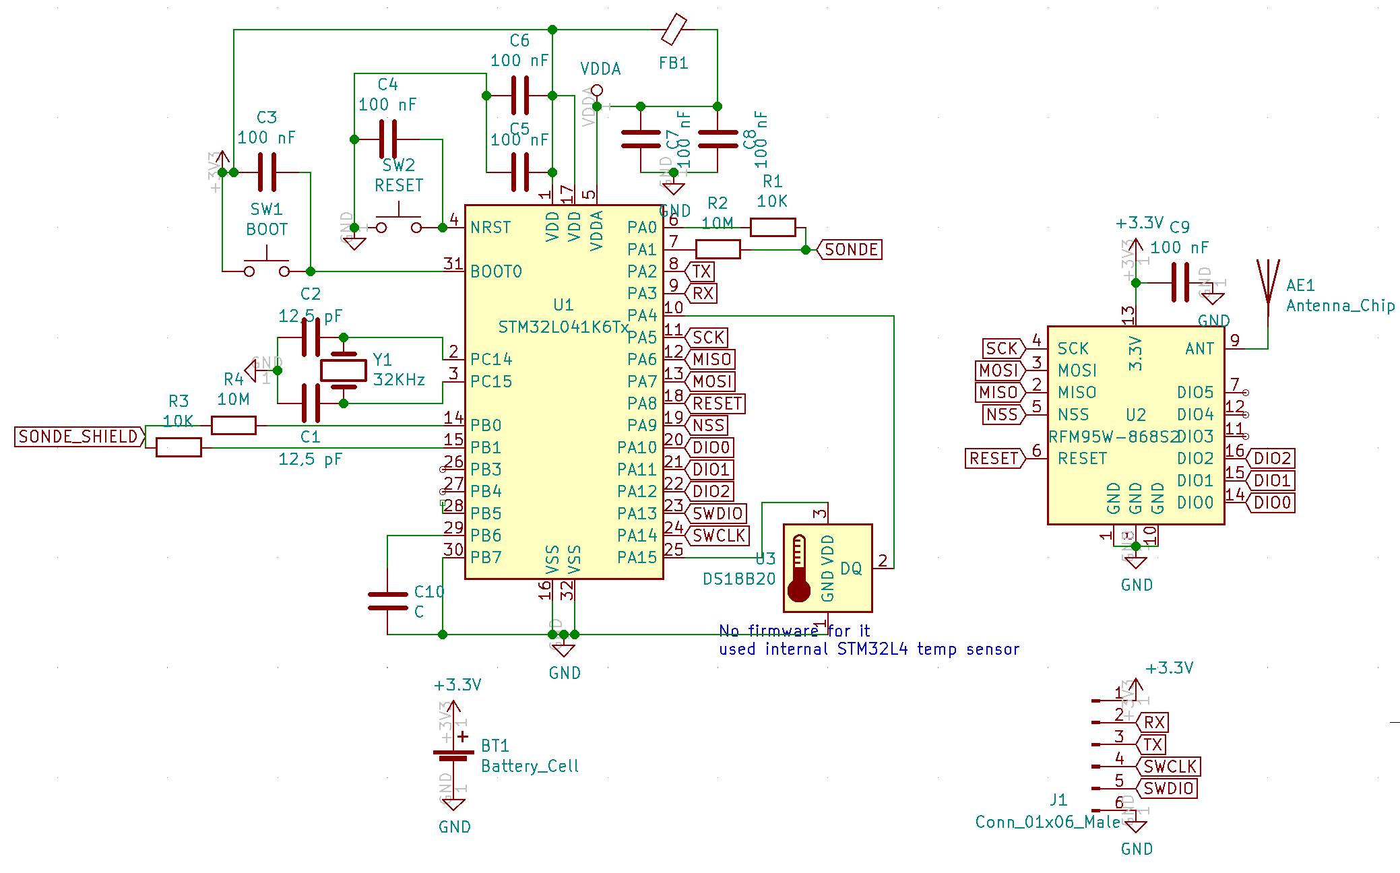
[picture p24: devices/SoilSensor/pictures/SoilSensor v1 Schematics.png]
Schematics Preview
  - 
- [SoilSensor.kicad_pcb](KiCad/SoilSensor.kicad_pcb)
  - PCB Overview
  - PCB Close View Front
  - PCB Close View Rear
  - [SVG for soil sonde](pictures/soilSonde.svg)
    - edited with [Inkscape](https://inkscape.org)
    - imported to KiCad with [svg2shenzhen](https://github.com/badgeek/svg2shenzhen) plugin.
    - Sonde Preview
- [3D Printed cage](cage) mount with battery:
  - Cage Preview
  - Cage Complete

- BUGS:
  - The boot input is missing a pull-up so sometimes the PCB boots into the bootloader after power-up. See [front picture](pictures/SoilSensor_v1_PCB_close_view_front.jpg) on how to manually add one.

## Soil Sensor v0

This was designed using [Fritzing](https://fab.fritzing.org/) and an Arduino pro mini. I only have a single instance running since the PCB had multiple bugs. Also the consumption was not so great since the used sensor required quite a lot of power to provide an stable read after waking up. Therefore it is not recommend to use this version.

- [Aisler PCB project](https://aisler.net/p/HJICOQLU)
- [Fritzing files](Fritzing-v0_only)
- BUGS: too many - very early prototype

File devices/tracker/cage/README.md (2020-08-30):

# Box for door Sensor
There are 2 files for each sensor, box and lid.

Pieces Preview

## Options used for printing
- Layer height __0.2 mm__
- Nozzle diameter __0.4 mm__
- Material __PETG__

## Mount indications

You would need nine 4mm long M2 screws, although it is not entirely necessary because the board and lid are very well fitted in the box. You can also use two 4mm long M3 screws to hold sensor Lidar.

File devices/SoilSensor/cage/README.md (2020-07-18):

# Box for Sensor
There are 2 files for each sensor, box and cover. In the file name it is indicated for which board version each file is.

Pieces Preview

## Options used for printing
- Layer height __0.2 mm__
- Nozzle diameter __0.4 mm__
- Material __PETG__

## Mount indications

You would need 4mm long M2 screws, although it is not entirely necessary because the board is very well fitted in the box. It can be improved by sealing with silicone the part where the sensor comes out. It is also recommended to apply some protection to the cover of the box to better withstand  outside, it is better that it ends up having a light or reflective color to prevent it from heating up in sunlight.

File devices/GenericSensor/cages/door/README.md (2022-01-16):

# Box for door Sensor
There are 2 files for each sensor, box and [reed switch](https://www.explainthatstuff.com/howreedswitcheswork.html) holder.

- [Box preview](https://a360.co/3GygWqv)
- [Fusion 360 model](Lora-generic-box.f3z)
- holder preview

## Options used for printing
- Layer height __0.2 mm__
- Nozzle diameter __0.4 mm__
- Material __PETG__

## Mount indications

You will need 2x 6mm long M2 screws. Use double-sided tape to secure the box, the reed switch holder, and the magnets.

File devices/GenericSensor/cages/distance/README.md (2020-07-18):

# Box for distance sensor
There are 2 files for each sensor, box and cover.

Pieces Preview

## Options used for printing
- Layer height __0.2 mm__
- Nozzle diameter __0.4 mm__
- Material __PETG__

## Mount indications

You would need 4mm long M2 screws, although it is not entirely necessary because the board is very well fitted in the box. An extra M2 screw is needed to mount a handle under the PCB, to make easier removing the box from the cover. The cover is fixed to the wall with 3mm screws. It is also recommended to apply some protection to the cover of the box to better withstand  outside, it is better that it ends up having a light or reflective color to prevent it from heating up in sunlight.

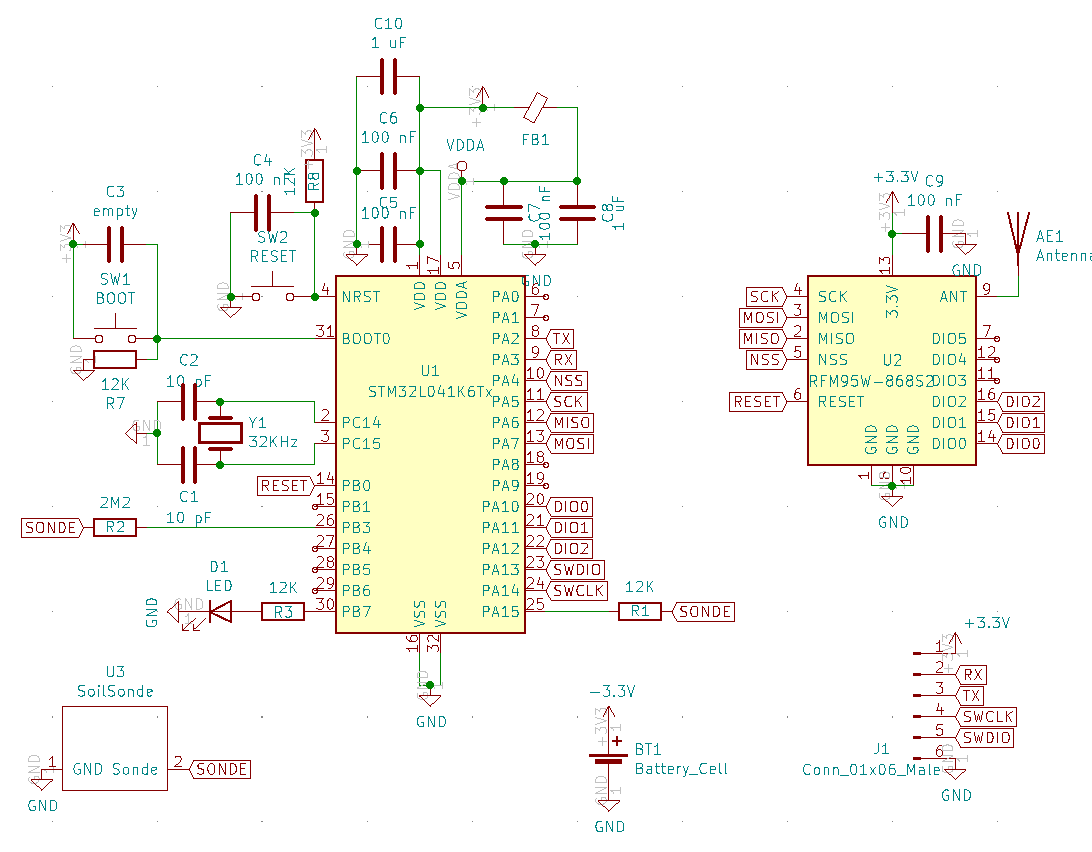
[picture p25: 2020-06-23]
devices/SoilSensor/pictures/SoilSensor v2 Schematics.png

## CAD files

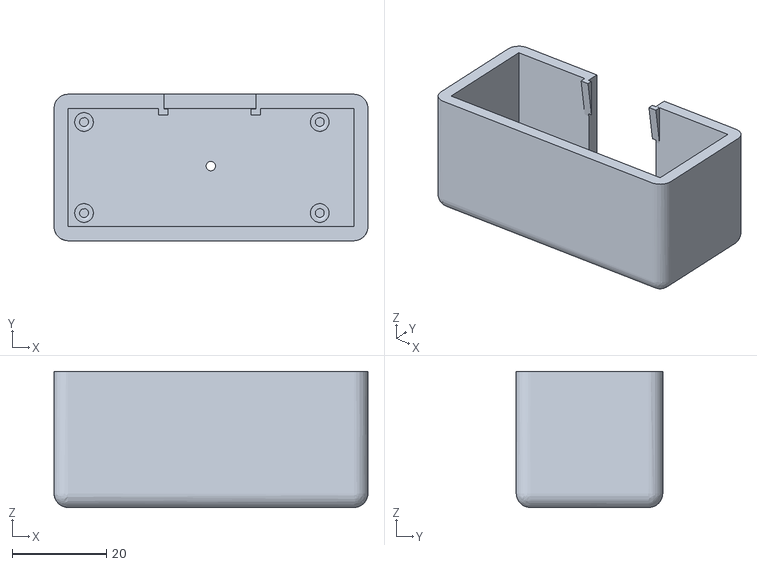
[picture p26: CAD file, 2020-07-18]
devices/GenericSensor/cages/distance/Wireless_Distance_Sensor_box_v1_1.stl
66.6 x 31.1 x 28.8

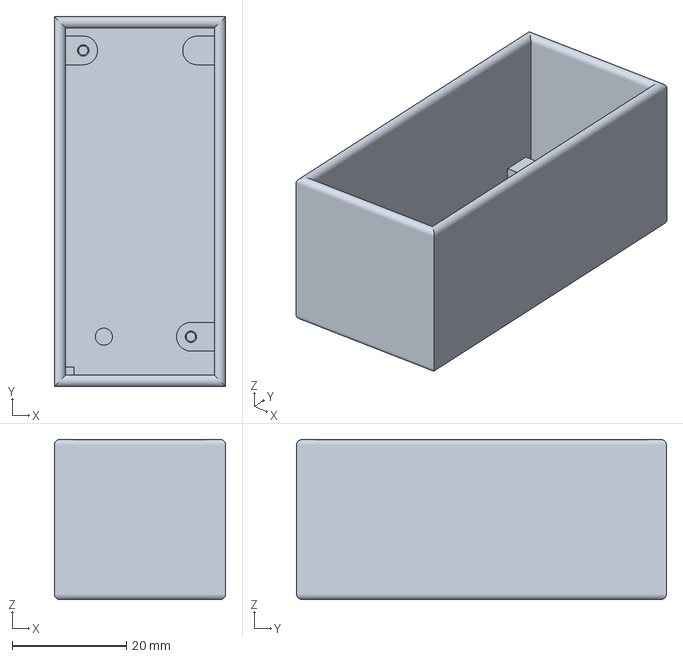
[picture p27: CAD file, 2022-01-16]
devices/GenericSensor/cages/door/lorawan-door-box.3mf
30.0 x 64.7 x 28.0 mm

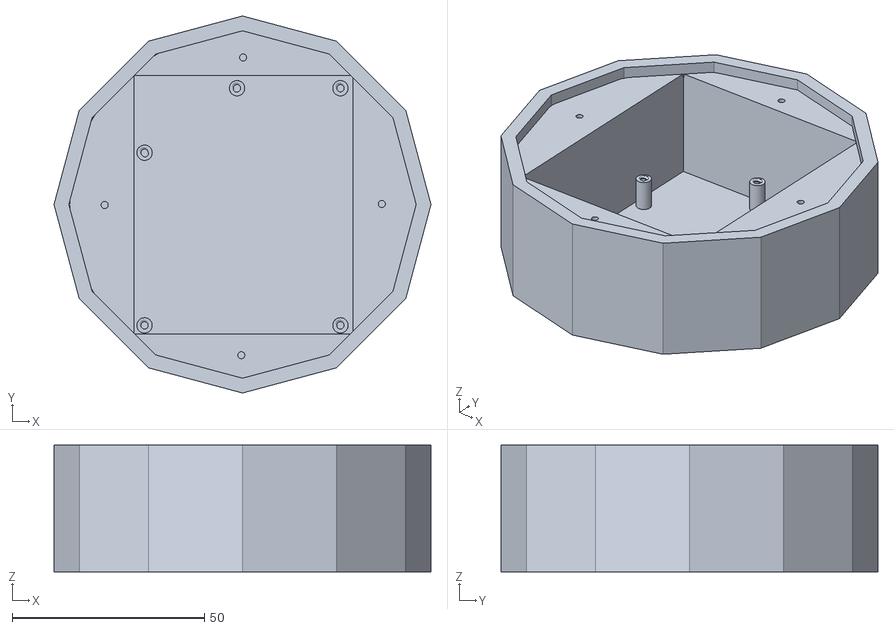
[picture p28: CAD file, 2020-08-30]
devices/tracker/cage/Tracker_cage.stl
98.0 x 98.0 x 33.0

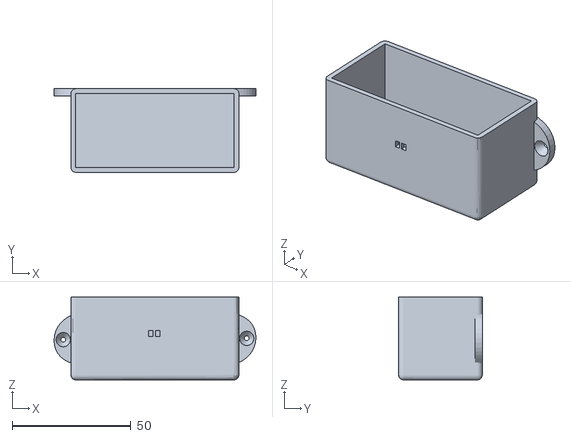
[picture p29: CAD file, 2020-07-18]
devices/GenericSensor/cages/distance/Wireless_Distance_Sensor_cover_v1_1.stl
85.0 x 35.2 x 34.8

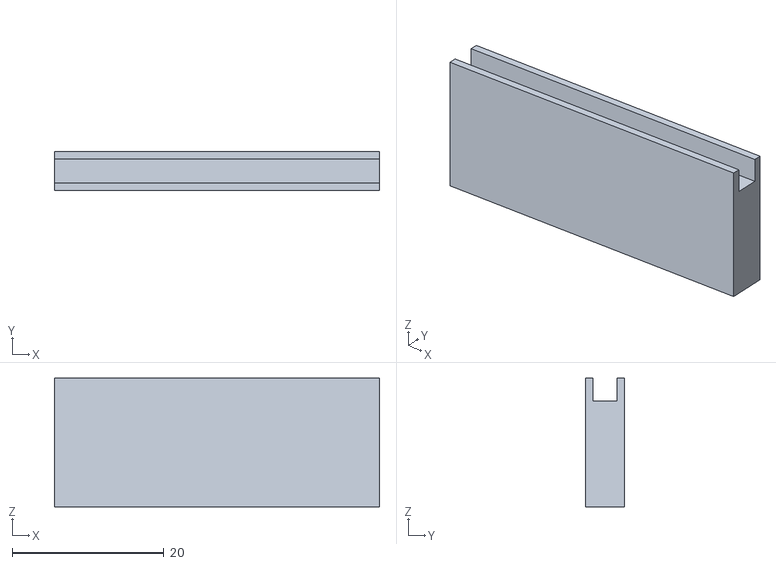
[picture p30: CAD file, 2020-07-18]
devices/GenericSensor/cages/door/Reed_Switch_Holder_H17mm.stl
42.9 x 5.10 x 17.0

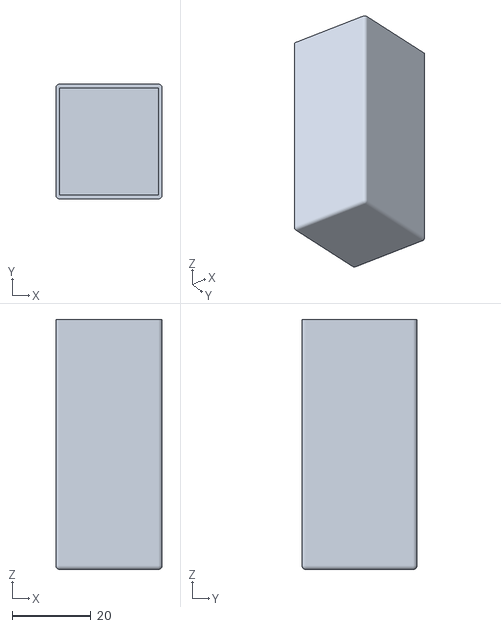
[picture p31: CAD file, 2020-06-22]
devices/SoilSensor/cage/Wireless_Soil_Moisture_Sensor_cover_v2_1.stl
26.9 x 29.1 x 63.3

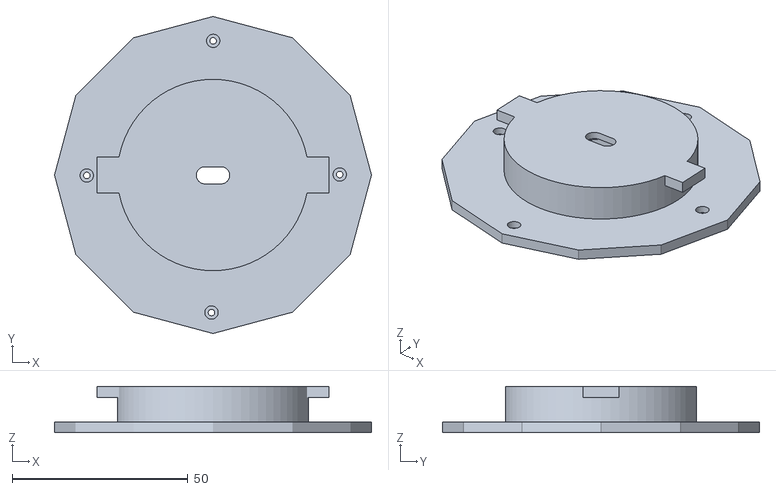
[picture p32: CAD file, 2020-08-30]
devices/tracker/cage/Tracker_lid.stl
90.3 x 90.3 x 13.2

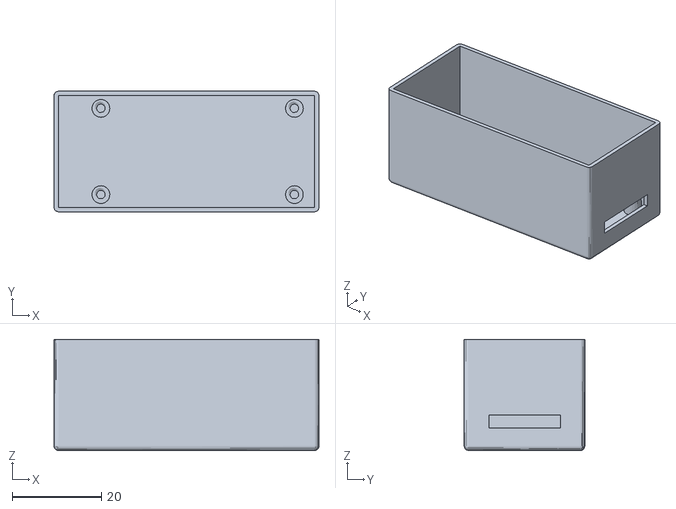
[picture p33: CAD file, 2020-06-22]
devices/SoilSensor/cage/Wireless_Soil_Moisture_Sensor_box_v2_1.stl
59.3 x 27.0 x 24.9

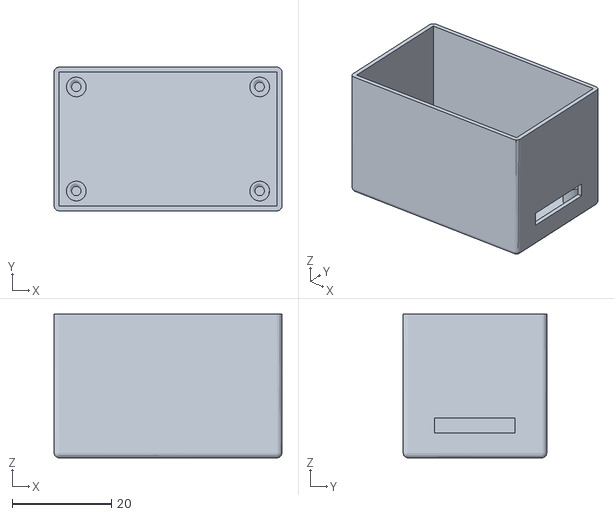
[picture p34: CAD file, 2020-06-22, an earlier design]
devices/SoilSensor/cage/Wireless_Soil_Moisture_Sensor_box_v1_4.stl
46.0 x 29.0 x 29.0

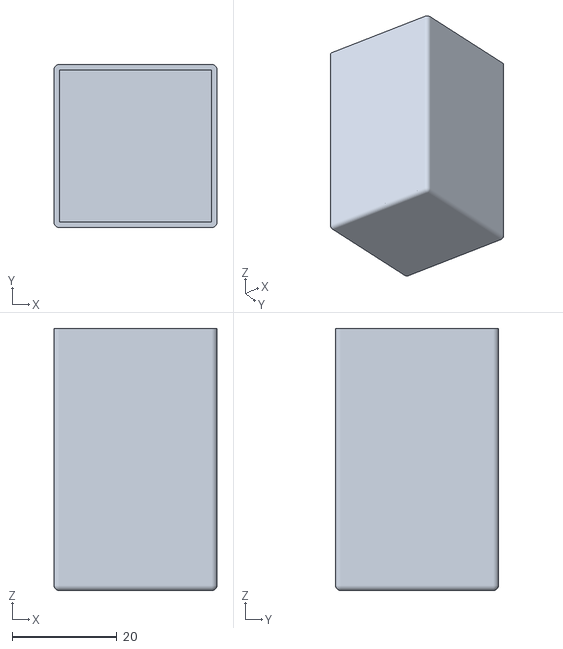
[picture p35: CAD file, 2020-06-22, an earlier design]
devices/SoilSensor/cage/Wireless_Soil_Moisture_Sensor_cover_v1_4.stl
31.1 x 31.1 x 50.0

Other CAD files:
devices/GenericSensor/cages/door/Lora-generic-box.f3z

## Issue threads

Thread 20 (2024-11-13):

Target MCU Soil Sensor

coustam, 2024-11-13:
When reading the readme regarding the V2 sensor :

The firmware shall be loaded as such : pio run -t upload -e soilsensor_v2_L4

When checking in this configuration :
[env:soilsensor_v2_L4]
	extends = base_soilsensor_2
	**board = nucleo_l412kb**

Meaning the target MCU is  : STM32L412KB
This one have a touch sensor https://www.st.com/en/microcontrollers-microprocessors/stm32l412kb.html

But the project on aisler is for STM32L041K6Tx
Also the stm32L041K6Tx does not have touch sensor.

If I understandand correctly your idea is what you want to use as peripheral ?

Would you please cross check if the Hardware in  aisler/kickad project and Firmware would be compatible ?

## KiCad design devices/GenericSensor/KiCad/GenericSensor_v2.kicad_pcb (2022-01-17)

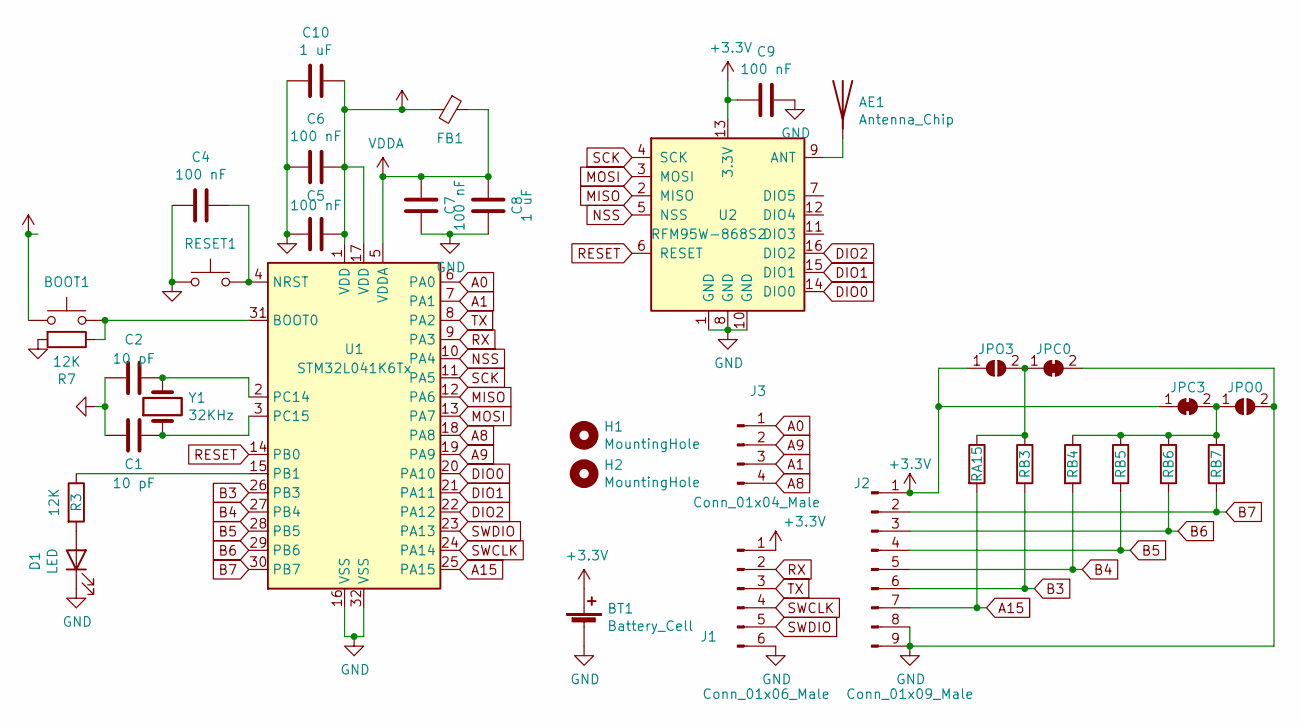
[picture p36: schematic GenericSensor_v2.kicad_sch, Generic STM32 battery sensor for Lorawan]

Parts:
AE1: Antenna_Chip; Texas_SWRA416_868MHz_915MHz
BOOT1: BOOT; SW_SPST_TL3342
BT1: Battery_Cell; CR123_holder
C1, C2: 10 pF; C_0805_2012Metric
C4, C5, C6, C7, C9: 100 nF; C_0805_2012Metric
C8, C10: 1 uF; C_0805_2012Metric
D1: LED; D_0805_2012Metric
FB1: Ferrite_Bead_Small; R_0805_2012Metric
H1, H2: MountingHole; MountingHole_2.2mm_M2
J1: Conn_01x06_Male; PinHeader_1x06_P2.54mm_Vertical
J2: Conn_01x09_Male; PinHeader_1x09_P2.54mm_Vertical
J3: Conn_01x04_Male; PinHeader_2x02_P2.54mm_Vertical
JPC0, JPC3: SolderJumper_2_Bridged; SolderJumper-2_P1.3mm_Bridged_Pad1.0x1.5mm
JPO0, JPO3: SolderJumper_2_Open; SolderJumper-2_P1.3mm_Open_Pad1.0x1.5mm
R3, R7: 12K; R_0805_2012Metric
RA15: PU; R_0805_2012Metric
RB3, RB4, RB5, RB6, RB7: PU; R_0805_2012Metric
RESET1: RESET; SW_SPST_TL3342
U1: STM32L041K6Tx; LQFP-32_7x7mm_P0.8mm
U2: RFM95W-868S2; HOPERF_RFM9XW_SMD
Y1: 32KHz; Crystal_SMD_3215-2Pin_3.2x1.5mm

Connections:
+3V3: BOOT1.1, BT1.1 (+), C5.1, C6.1, C9.2, C10.1, FB1.2, J1.1, J2.1, JPC3.1 (A), JPO3.1 (A), U1.1 (VDD), U1.17 (VDD), U2.13 (3.3V)
A0: J3.1, U1.6 (PA0)
A1: J3.3, U1.7 (PA1)
A8: J3.4, U1.18 (PA8)
A9: J3.2, U1.19 (PA9)
A15: J2.7, RA15.2, U1.25 (PA15)
B3: J2.6, RB3.2, U1.26 (PB3)
B4: J2.5, RB4.2, U1.27 (PB4)
B5: J2.4, RB5.2, U1.28 (PB5)
B6: J2.3, RB6.2, U1.29 (PB6)
B7: J2.2, RB7.2, U1.30 (PB7)
DIO0: U1.20 (PA10), U2.14 (DIO0)
DIO1: U1.21 (PA11), U2.15 (DIO1)
DIO2: U1.22 (PA12), U2.16 (DIO2)
GND: BT1.2 (-), C1.2, C2.2, C4.2, C5.2, C6.2, C7.1, C8.1, C9.1, C10.2, D1.1 (K), J1.6, J2.8, J2.9, JPC0.2 (B), JPO0.2 (B), R7.2, RESET1.1, U1.16 (VSS), U1.32 (VSS), U2.1 (GND), U2.8 (GND), U2.10 (GND)
MISO: U1.12 (PA6), U2.2 (MISO)
MOSI: U1.13 (PA7), U2.3 (MOSI)
NSS: U1.10 (PA4), U2.5 (NSS)
unnamed: AE1.1 (A), U2.9 (ANT)
unnamed: BOOT1.2, R7.1, U1.31 (BOOT0)
unnamed: C1.1, U1.3 (PC15), Y1.1
unnamed: C2.1, U1.2 (PC14), Y1.2
unnamed: C4.1, RESET1.2, U1.4 (NRST)
unnamed: D1.2 (A), R3.2
unnamed: JPC0.1 (A), JPO3.2 (B), RA15.1, RB3.1
unnamed: JPC3.2 (B), JPO0.1 (A), RB4.1, RB5.1, RB6.1, RB7.1
unnamed: R3.1, U1.15 (PB1)
RESET: U1.14 (PB0), U2.6 (RESET)
RX: J1.2, U1.9 (PA3)
SCK: U1.11 (PA5), U2.4 (SCK)
SWCLK: J1.4, U1.24 (PA14)
SWDIO: J1.5, U1.23 (PA13)
TX: J1.3, U1.8 (PA2)
VDDA: C7.2, C8.2, FB1.1, U1.5 (VDDA)

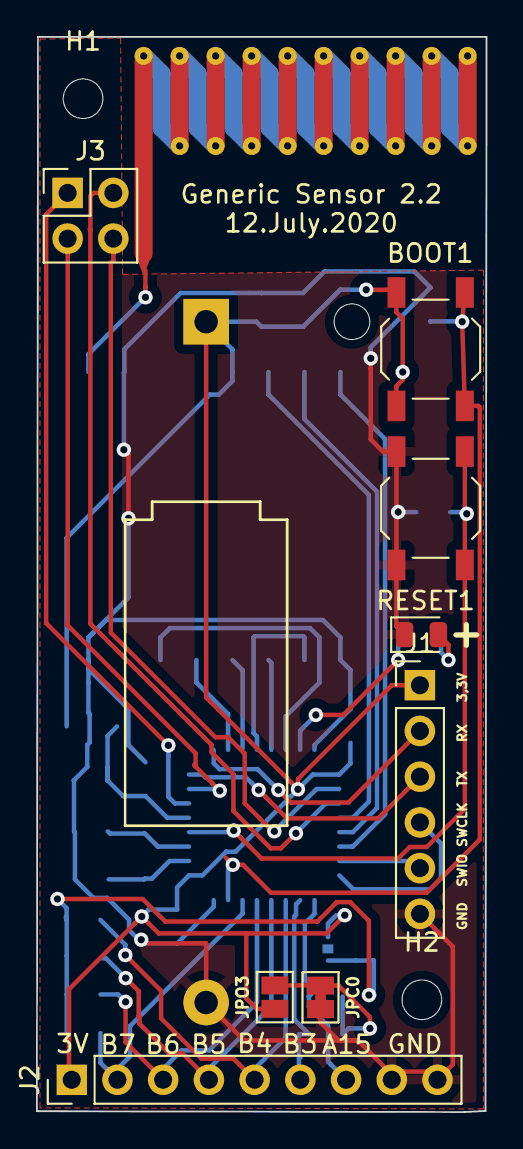
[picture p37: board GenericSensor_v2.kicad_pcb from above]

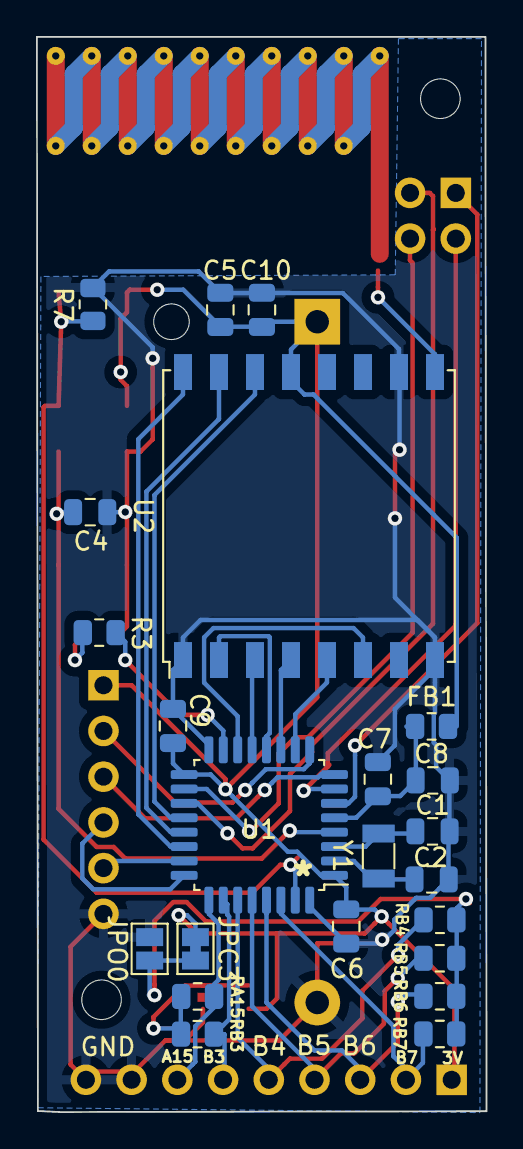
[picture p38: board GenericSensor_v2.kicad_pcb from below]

Board: 2 copper layers, 25.0 x 59.7 mm, 35 parts (23 on the bottom side), 34 nets.

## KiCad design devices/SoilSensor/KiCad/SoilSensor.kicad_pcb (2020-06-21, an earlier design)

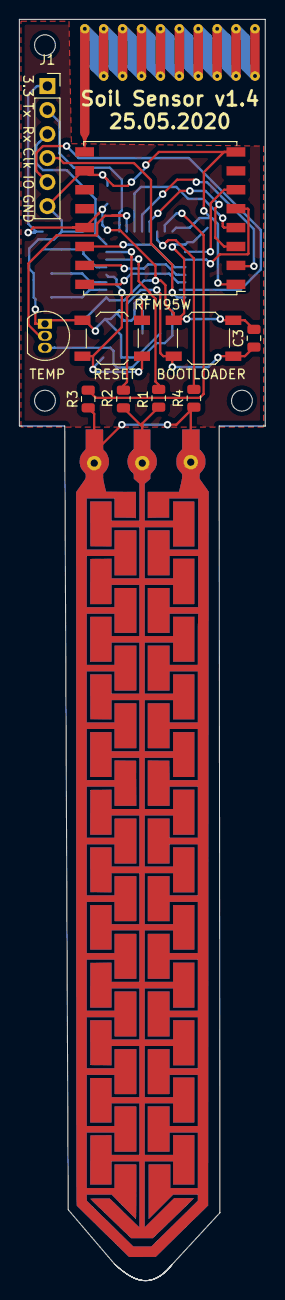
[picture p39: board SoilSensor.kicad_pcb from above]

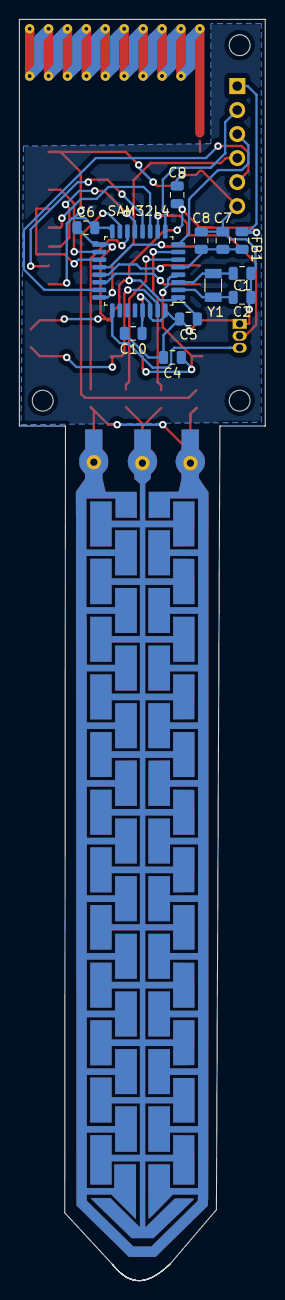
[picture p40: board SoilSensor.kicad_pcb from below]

Board: 2 copper layers, 26.0 x 133.4 mm, 25 parts (12 on the bottom side), 29 nets.

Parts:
 : MountingHole_2.2mm_M2
AE1: Antenna_Chip; Texas_SWRA416_868MHz_915MHz
BOOTLOADER: BOOT; SW_SPST_TL3342
C1, C2: 12,5 pF; C_0805_2012Metric
C3, C4, C5, C6, C7, C8, C9: 100 nF; C_0805_2012Metric
C10: C; C_0805_2012Metric
FB1: Ferrite_Bead_Small; R_0805_2012Metric
J1: Conn_01x06_Male; PinSocket_1x06_P2.54mm_Vertical
R1, R3: 10K; R_0805_2012Metric
R2, R4: 10M; R_0805_2012Metric
RESET: RESET; SW_SPST_TL3342
RFM95W: RFM95W-868S2; HOPERF_RFM9XW_SMD
Ref**: Val**; soilSonde
SAM32L4: STM32L041K6Tx; LQFP-32_7x7mm_P0.8mm
TEMP: DS18B20; TO-92_Inline
Y1: 32KHz; Crystal_SMD_3215-2Pin_3.2x1.5mm

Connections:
+3V3: BOOTLOADER.1, C3.2, C5.1, C6.1, C9.2, FB1.2, J1.1, RFM95W.13, SAM32L4.1, SAM32L4.17
DIO0: RFM95W.14, SAM32L4.20
DIO1: RFM95W.15, SAM32L4.21
DIO2: RFM95W.16, SAM32L4.22
GND: C1.2, C2.2, C4.2, C5.2, C6.2, C7.1, C8.1, C9.1, C10.2, J1.6, RESET.1, RFM95W.1, RFM95W.8, RFM95W.10, SAM32L4.16, SAM32L4.30, SAM32L4.32, TEMP.1
MISO: RFM95W.2, SAM32L4.12
MOSI: RFM95W.3, SAM32L4.13
NSS: RFM95W.5, SAM32L4.19
unnamed: AE1.1, RFM95W.9
unnamed: C1.1, SAM32L4.3, Y1.1
unnamed: C2.1, SAM32L4.2, Y1.2
unnamed: BOOTLOADER.2, C3.1, SAM32L4.31
unnamed: C4.1, RESET.2, SAM32L4.4
unnamed: C10.1, SAM32L4.29
unnamed: R1.1, SAM32L4.6
unnamed: R2.1, SAM32L4.7
unnamed: R3.2, SAM32L4.15
unnamed: R4.2, SAM32L4.14
unnamed: SAM32L4.10, TEMP.2
unnamed: SAM32L4.25, TEMP.3
RESET: RFM95W.6, SAM32L4.18
RX: J1.3, SAM32L4.8
SCK: RFM95W.4, SAM32L4.11
SONDE: R1.2, R2.2, Ref**.2
SONDE_SHIELD: R3.1, R4.1, Ref**.1
SWCLK: J1.4, SAM32L4.24
SWDIO: J1.5, SAM32L4.23
TX: J1.2, SAM32L4.9
VDDA: C7.2, C8.2, FB1.1, SAM32L4.5

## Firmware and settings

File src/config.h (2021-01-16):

#ifndef config_h
#define config_h

#include "Arduino.h"
#include "devices.h"

//Device config

#ifndef DEBUG
  #define DEBUG 0 
#endif
#ifndef DEFAULT_MAX_SKIPED_MEASUREMENTS
  #if DEBUG
    #define DEFAULT_MAX_SKIPED_MEASUREMENTS 1
  #else
    #define DEFAULT_MAX_SKIPED_MEASUREMENTS 60
  #endif
#endif
#define DEFAULT_AVERAGE_MEASUREMENTS 5
#define PAUSE_SECONDS_AFTER_WATCHDOG 600

struct lorawan_keys_t {
  uint8_t appkey[16];
  uint64_t deveui;
  uint64_t appeui;
};

struct device_config_t {
  //Common part
  uint8_t version_config;
  uint8_t version;
  uint8_t is_debug;
  uint8_t reserved;
  uint16_t measure_interval_s;
  uint8_t measure_average;
  uint8_t max_skiped_measurements;
  //device specific
  device_config_device_t device;
};

#define UID_BYTES_LENGTH 12

extern lorawan_keys_t lorawan_keys;
extern device_config_t device_config;
extern void set_device_specific_config(device_config_device_t& specific_device_config); //implemented differently for each device
void init_device_config(bool reset=false);
void write_device_config(device_config_t &device_config);
void print_buildinfo();



//channels
enum cayenneLPP_channels {
    SENSOR_VERSION_CHANNEL=1,
    SENSOR_BATTERY_CHANNEL=3,
    SENSOR_SOIL_VOLTAGE_CHANNEL=4,
    SENSOR_SOIL_HUMIDITY_CHANNEL=40,
    SENSOR_TEMP_CHANNEL=41,
    SENSOR_DISTANCE_CHANNEL=42,
    SENSOR_PEAK_SIGNAL_CHANNEL=43,
    SENSOR_LUMINOSITY_CHANNEL=44,
    SENSOR_DOOR_1_CHANNEL=45,
    SENSOR_DOOR_2_CHANNEL=46,
    SENSOR_DOOR_3_CHANNEL=47,
    SENSOR_DOOR_4_CHANNEL=48,
    SENSOR_GPS_POS_CHANNEL=49,
    SENSOR_GPS_SIV_CHANNEL=50,
    SENSOR_ACCELEROMETER_CHANNEL=51,
    SENSOR_MOVING_CHANNEL=52
};

//Sensor settings
#if defined(ARDUINO_ARCH_AVR)
  #define SENSOR_AVR_SOIL 1

  #define SENSOR_ADC_REFERENCE INTERNAL
#elif defined(ARDUINO_ARCH_STM32)

  #if defined(STM32L0xx)
    //See https://www.mouser.de/datasheet/2/389/stm32l010k8-1851374.pdf
    #define ADC_VREFINT_3V0_30C_ADDR 0x1FF80078
  #elif defined(STM32L4xx)
    //See https://www.mouser.de/datasheet/2/389/stm32l412c8-1851177.pdf
    #define ADC_VREFINT_3V0_30C_ADDR 0x1FFF75AA
    #define ADC_TEMP_3V0_30C_ADDR  0x1FFF75A8 
    #define ADC_TEMP_3V0_130C_ADDR 0x1FFF75CA
  #else
    #error Unknown STM32 MMU
  #endif
#else
  #error No config available for MCU
#endif

//Serial port
#define serialPortSpeed 115200
#define log_flush Serial.flush
#define log_error Serial.print
#define log_error_ln Serial.println
#define log_warning Serial.print
#define log_warning_ln Serial.println
#define log_info Serial.print
#define log_info_ln Serial.println
#if DEBUG
  #define log_debug Serial.print
  #define log_debug_ln Serial.println
#else
  #define log_debug if (false) Serial.print
  #define log_debug_ln if (false) Serial.println
#endif

#define Q(x) #x
#define QUOTE(x) Q(x)
#define GIT_COMMIT_ID QUOTE(PIO_SRC_REV)

#ifndef UNUSED
  #define UNUSED(x) x=x
#endif

//Lorawan
#define USE_ADR 1
// Schedule TX every this many seconds (might become longer due to duty
// cycle limitations).
#ifdef TX_INTERVAL
  //Use directly
#elif DEBUG
  const uint32_t TX_INTERVAL=60;
#else
  const uint32_t TX_INTERVAL=60;
#endif

#define LMIC_CLOCK_ERROR_PERCENTAGE 5




#endif //config_h

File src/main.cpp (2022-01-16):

#include "config.h"
#include "sleep.h"
#include "lorawan.h"
#include "sensor.h"
//#include "STM32LowPower.h"
#ifdef IWDG_TIME_S
#include "IWatchdog.h"
#endif

void setup() {

    #ifdef DEBUG_DURING_SLEEP
        HAL_DBGMCU_EnableDBGStopMode();
    #elif defined(NO_DEBUG_DURING_SLEEP)
        HAL_DBGMCU_DisableDBGStopMode();
    #endif

    sleep_setup();
    Serial.begin(serialPortSpeed);
    
    #ifdef IWDG_TIME_S
      if (IWatchdog.isReset(/* clear */ true)) {
        log_info_ln(F("Reset from watchdog -> sleeping"));
        #ifdef PIN_STATUS_LED
          //Blink error
          pinMode(PIN_STATUS_LED, OUTPUT);
          for (size_t i=0;i<5;i++) {
            digitalWrite(PIN_STATUS_LED, HIGH);
            delay(200);
            digitalWrite(PIN_STATUS_LED, LOW);
            delay(200);
          }
        #endif
        log_flush();
        do_sleep(PAUSE_SECONDS_AFTER_WATCHDOG * 1000);
      }

      //Enable watchdog
      IWatchdog.begin(IWDG_TIME_S*1000*1000);
      
    #endif

    //Give a few seconds to connect programmer
    delay(5*1000);
    
    init_device_config();
    print_buildinfo();
    
    Sensors::setup();
    #ifdef PIN_STATUS_LED
      pinMode(PIN_STATUS_LED, OUTPUT);
      digitalWrite(PIN_STATUS_LED, HIGH);
    #endif
  
    lorawan_setup();
    
    log_info_ln(F("Starting"));
    log_flush();

    #ifdef PIN_STATUS_LED
      pinMode(PIN_STATUS_LED, OUTPUT);
      digitalWrite(PIN_STATUS_LED, LOW);
    #endif
}

CayenneLPP lpp(51);
void loop_work() {

    #ifdef IWDG_TIME_S
      IWatchdog.reload();
    #endif
    
    lorawan_resume();
    
    //Measure
    bool mustSend = Sensors::measure(lpp);

    // Start job (sending automatically starts OTAA too)
    if (mustSend) lorawan_send(lpp.getBuffer(), lpp.getSize());

    lorawan_suspend();

}

void loop() {
  loop_periodically(device_config.measure_interval_s*1000, loop_work); 
  //log_info(F("WAIT"));
  //while(1){IWatchdog.reload();delay(5*1000);};
}

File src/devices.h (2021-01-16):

#include "Arduino.h"

#if defined(SENSOR_SOIL_AVR)
    #define DEVICE_CONFIG_VERSION 1
    struct device_config_device_t {
        //Soil sensor
    };
    #define SENSOR_SOIL_EXTERNAL_AVR
#elif defined(SENSOR_SOIL_SMT32)
    #define DEVICE_CONFIG_VERSION 4
    struct device_config_device_t {
        //Soil sensor
        uint16_t min_s;
        uint16_t max_s;
        uint8_t min_percentage_v_2_send;
        uint8_t min_percentage_t_2_send;
        uint8_t min_percentage_s_2_send;
    };
    #define SENSOR_SOIL_CAPACITY
#elif defined(SENSOR_GENERIC_BASIC_SMT32)
    #define DEVICE_CONFIG_VERSION 1
    struct device_config_device_t {
        //Generic basic sensor
        uint8_t min_percentage_v_2_send;
        uint8_t min_percentage_t_2_send;
    };
#elif defined(SENSOR_GENERIC_DISTANCE_SMT32)
    #define DEVICE_CONFIG_VERSION 3
    struct device_config_device_t {
        //Distance sensor
        uint8_t min_percentage_v_2_send;
        uint8_t min_percentage_t_2_send;
        uint8_t min_percentage_distance_2_send;
        uint8_t unused;
        int16_t distance_offset;
    };
    #define SENSOR_LIDAR_VL53L1X_SPARFUNK
    //#define SENSOR_LIDAR_VL53L1X_SHORT
    //#define SENSOR_LIDAR_VL53L1X_MEDIUM
#elif defined(SENSOR_GENERIC_DOOR_SMT32)
    #define DEVICE_CONFIG_VERSION 1
    struct device_config_device_t {
        //door sensor
        uint8_t min_percentage_v_2_send;
        uint8_t min_percentage_t_2_send;
    };
    #define SENSOR_DOOR_REED
    //send each 6 hours
    #define TX_INTERVAL 3600
    #define DEFAULT_MAX_SKIPED_MEASUREMENTS 6
#elif defined(SENSOR_GENERIC_TRACKER_SMT32)
    #define DEVICE_CONFIG_VERSION 2
    struct device_config_device_t {
        //door sensor
        uint8_t min_percentage_v_2_send;
        uint8_t min_percentage_t_2_send;
        uint8_t min_percentage_distance_2_send;
        uint8_t min_acceleration_dg_2_send;
        uint8_t min_possition_change_mg_2_send;
        uint8_t min_altitude_change_m_2_send;
        int16_t distance_offset;
    };
    //Sensors
    #define SENSOR_GPS_UBLOCK
    //#define SENSOR_LIDAR_VL53L1X_POLOLU
    #define SENSOR_LIDAR_VL53L1X_SPARFUNK
    #define SENSOR_LIDAR_VL53L1X_SHORT
    //#define SENSOR_LIDAR_VL53L1X_MEDIUM
    #define SENSOR_ACCELEROMETER_LIS3DH

    //Config
    //measure each 6 hours (quiet)
    #ifndef TX_INTERVAL
        #define TX_INTERVAL 6*3600
    #endif
    #ifndef DEFAULT_MAX_SKIPED_MEASUREMENTS
        #define DEFAULT_MAX_SKIPED_MEASUREMENTS 1
    #endif
    //Send each 10 minutes (movement)
    #ifndef TX_FAST_INTERVAL
        #define TX_FAST_INTERVAL_S 600
    #endif
#else
    #error "Unkown device type"
#endif

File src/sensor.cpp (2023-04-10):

#include "sensor.h"
#include "config.h"

#include "sleep.h"
#include "Wire.h"

// Average
uint32_t Sensor::averageAnalogInput(uint32_t pin, uint8_t measurements) {
  uint32_t total = 0;
  for (uint8_t i=0; i<measurements; i++){
    total += analogRead(pin);
  }
  return total / measurements;

}

bool Sensors::iv_firstTime_setup=true;
bool Sensors::iv_ready=false;
uint8_t Sensors::skippedMeasurements=0;

std::vector<Sensor*>& Sensors::sensor_pointers(){
    static std::vector<Sensor*>* ans = new std::vector<Sensor*>;
    return *ans;
}

void Sensors::set_config(device_config_device_t& specific_device_config) {
    for (size_t i=0; i < sensor_pointers().size(); i++) {
        sensor_pointers()[i]->set_config(specific_device_config);
    }
}        
void Sensors::setup() {
    if (iv_firstTime_setup) {
        allInput();
        #ifdef ADC_RESOLUTION
            analogReadResolution(ADC_RESOLUTION);
        #endif
    }
    if (not iv_ready) {
        Wire.begin();
        //Wire.setClock(400000); // use 400 kHz I2C 
        //Wire.setClock(10000); // use 100 kHz I2C 
        for (size_t i=0; i < sensor_pointers().size(); i++) {
            sensor_pointers()[i]->setup();
        }
    }
    iv_firstTime_setup = false;
    iv_ready = true;
}

void Sensors::sleep() {
  if (iv_ready) {
        //Wire.setClock(400000); // use 400 kHz I2C 
        //Wire.setClock(10000); // use 100 kHz I2C 
        for (size_t i=0; i < sensor_pointers().size(); i++) {
            sensor_pointers()[i]->sleep();
        }

        Wire.end();
        pinMode(PB6, OUTPUT);
        digitalWrite(PB6, LOW);
        pinMode(PB7, OUTPUT);
        digitalWrite(PB7, LOW);
    }
    iv_ready = false;
}


bool Sensors::measure(CayenneLPP& lpp){
    
    //Init sensor
    setup();
    
    //Read sensors
    bool enough_change = false;
    for (size_t i=0; i < sensor_pointers().size(); i++) {
        if (sensor_pointers()[i]->measure()) {
            enough_change = true;
            log_info(sensor_pointers()[i]->get_name());
            log_info_ln(F(" changed -> sending measurement"));
            log_flush();
        }
    }

    //Stop sensor
    sleep();
    
    //Check if we have skipped too many measurements
    if (skippedMeasurements >= device_config.max_skiped_measurements)
    {
        enough_change = true;
    }

    if (enough_change) {
        skippedMeasurements = 0; //Reset
        log_info_ln(F("Sending measurement"));
        log_flush();
        lpp.reset();
        lpp.addDigitalInput(SENSOR_VERSION_CHANNEL, device_config.version);
        for (size_t i=0; i < sensor_pointers().size(); i++) {
            sensor_pointers()[i]->send(lpp);
        }
    } else {

        //only count skipped in regular mode
        if (! is_fast_sleep() ){
            skippedMeasurements ++;
        }

        log_debug(F("Skipped sending measurement: "));
        log_debug_ln(skippedMeasurements);
        log_flush();
    }

  return enough_change;
}

void Sensors::allInput()
{
    log_debug_ln(F("Setting all pins as inputs"));
    #ifdef ARDUINO_ARCH_STM32
        pinMode(PA0, INPUT_PULLDOWN);
        pinMode(PA1, INPUT_PULLDOWN);
        //Serial port
        //pinMode(PA2, INPUT_PULLDOWN);
        //pinMode(PA3, INPUT_PULLDOWN);
        pinMode(PA4, INPUT_PULLDOWN);
        pinMode(PA5, INPUT_PULLDOWN);
        pinMode(PA6, INPUT_PULLDOWN);
        pinMode(PA7, INPUT_PULLDOWN);
        pinMode(PA8, INPUT_PULLDOWN);
        pinMode(PA9, INPUT_PULLDOWN);
        pinMode(PA10, INPUT_PULLDOWN);
        
        pinMode(PA11, INPUT_PULLDOWN);
        pinMode(PA12, INPUT_PULLDOWN);
        //WSI port
        //pinMode(PA13, INPUT_PULLDOWN);
        //pinMode(PA14, INPUT_PULLDOWN);
        pinMode(PA15, INPUT_PULLDOWN);

        pinMode(PB0, INPUT_PULLDOWN);
        pinMode(PB1, INPUT_PULLDOWN);
        pinMode(PB3, INPUT_PULLDOWN);
        pinMode(PB4, INPUT_PULLDOWN);
        pinMode(PB5, INPUT_PULLDOWN);
        pinMode(PB6, INPUT_PULLDOWN);
        pinMode(PB7, INPUT_PULLDOWN);
    #endif
}

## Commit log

2020-06-21 Initial public release
    [SoilSensor.kicad_pcb, SoilSensor.sch, SoilSensor_v2.kicad_pcb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]
2020-06-21 Fix name in devices.ini
2020-06-22 3D-printed box files for sensor cages
    [Wireless_Soil_Moisture_Sensor_box_v1_4.stl, Wireless_Soil_Moisture_Sensor_box_v2_1.stl, Wireless_Soil_Moisture_Sensor_cover_v1_4.stl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]
2020-06-23 Documment KiCad
    [SoilSensor.sch]
2020-06-28 rework for multi device
    [common_stm32.cpp, config.h, devices.h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]
2020-06-28 Rework documentantion
    [GenericSensor_v1.kicad_pcb, GenericSensor_v1.sch, SoilSensor.kicad_pcb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]
2020-07-04 Reset config when switching from debug to reset
    [config.h, lorawan.cpp]
2020-07-04 Working distance sensor
2020-07-04 Make version device specific
2020-07-04 Small fixes for distance
    [GenericSensor_v1.kicad_pcb, GenericSensor_v1.sch]
2020-07-04 Add basic sensor
2020-07-04 Add sleep after recovering from watchdog
    [battery_calculations.xlsx]
2020-07-05 Small revision -> 2.2
    [SoilSensor_v2.kicad_pcb, SoilSensor_v2.sch]
2020-07-11 Document howto add new devices
2020-07-11 Use stm32duino master
2020-07-11 Support to skip next sleep
    [sleep.cpp]
2020-07-11 Add door sensor
    [battery_calculations.xlsx]
2020-07-12 Version 7 - door sensor tested
    [battery_calculations.xlsx]
2020-07-12 Add PCB v2
    [GenericSensor_v2.kicad_pcb, GenericSensor_v2.sch]
2020-07-14 Added 3D piece files and pictures
    Added 3D piece files for Distance and door sensor.
    [Reed_Switch_Holder_H17mm.stl, Wireless_Distance_Sensor_box_v1_1.stl, Wireless_Distance_Sensor_cover_v1_1.stl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]
2020-07-26 WIP for tracker
    [GenericSensorMini_v1.kicad_pcb, GenericSensorMini_v1.sch, battery_calculations.xlsx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]
2020-08-19 Adding tracker - before class rework
    [tracker_v1.kicad_pcb, tracker_v1.sch]
2020-08-29 Add tracker pictures
    Added pictures to tracker project.
    [Tracker_cage.stl, Tracker_lid.stl]
2020-08-29 % not calculated correctly
    [soil_capacity.cpp]
2020-08-29 Do not count skipped measurements in fast mode
    [sensor.cpp, sleep.cpp]
2020-08-29 reset did not work
    [devices.h, door_reed.cpp]
2020-08-30 switch to use C lib from STM
2020-08-31 fix fast sleep time
    [accelerometer_LIS3DH.cpp, devices.h]
2020-08-31 if interrupt comes CPU wakes up even in disabled
2020-08-31 Reset filter reference on each measurement
    [accelerometer_LIS3DH.cpp]
2021-01-16 fix include case
2021-01-16 Fix case for Vector include
2022-01-16 refresh to latest libraries
    [GenericSensorMini_v1.kicad_pcb, GenericSensor_v1.kicad_pcb, GenericSensor_v2.kicad_pcb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]
2022-01-17 Add more 3D models
    [GenericSensor_v2.kicad_pcb]
2022-10-23 fix build errors due to old versions
    [lidar_VL53L1X_sparkfunk.cpp]
2023-04-10 log what sensor triggered the transmission
